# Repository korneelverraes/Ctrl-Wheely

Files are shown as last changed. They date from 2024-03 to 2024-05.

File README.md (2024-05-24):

# Ctrl-Wheely
*Optimalisatie van autodashboard-interactie door middel van een fysieke verplaatsbare knop in de middenconsole en een head-up display.* 

*Projectteam: Korneel Verraes; Warre Robbe*

24/05/2024

## Samenvatting
De nieuwe generatie auto's worden steeds meer uitgerust met slimme dashboards die een breed scala aan functies en flexibele interacties bieden. Grote touchscreens en weinig fysieke knoppen vinden hun weg in het ontwerp van nieuwe wagens. Dit ten gevolge van een besparing in de productie en een trend die bij de consument in goede aarde valt. Dergelijk ontwerp zorgt echter wel voor de nodige onveiligheid en afleiding. Ons doel: het dashboard herontwerpen met de gebruiker en zijn veiligheid in de belangstelling. Of, op welke (gebruiksvriendelijke) manier kunnen we de functies in het dashboard bedienen zonder onze focus op de weg te verliezen?

Wetenschappelijke artikels, _contextual inquiries_ en gebruikersbevragingen tonen aan dat de afleiding niet veroorzaakt wordt door de touchscreens zelf, maar door het gebrek aan tactiele feedback bij het bedienen van een touchscreen.

Met Ctrl-Wheely introduceren we een innovatief, gebruiksvriendelijk en veilig herontwerp van het autodashboard. Een combinatie van een head-up display (HUD), fysieke verplaatsbare knop en controlepaneel moet de bediening sneller en veiliger maken terwijl de ogen op de weg gehouden worden. De afleiding wordt hierbij tot een minimum beperkt.

<p align="center">
  
  
  
</p>

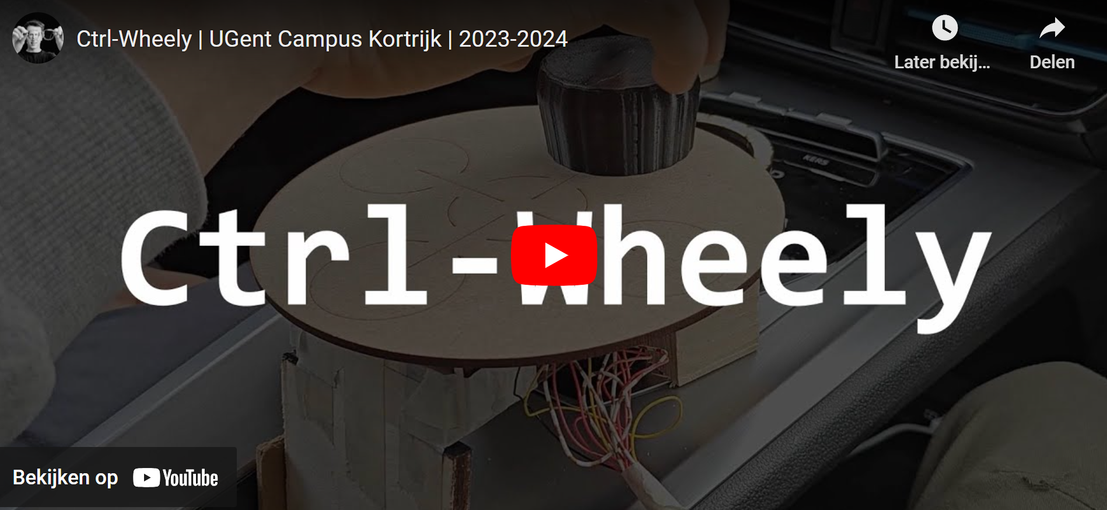
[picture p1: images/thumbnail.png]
[](https://www.youtube.com/watch?v=vWs9MYro9L0)

> [!NOTE]
> - Links naar volledige protocollen en reports zijn te vinden onder de [bijlagen](#bijlagen).
> - Ruwe data zoals foto's, video-opnames, _timetables_... zijn te vinden in de bijhorende protocollen en reports.
> - Volledige software, programma's en 3D-bestanden zijn te vinden in de map [files](/files).

## Introductie
In de hedendaagse auto's zijn touchscreens de standaard geworden, waarbij bestuurders verschillende functies bedienen, variërend van navigatie tot entertainment. Echter, het toenemende gebruik van touchscreens in auto's heeft zorgen gewekt over de veiligheid, met name de visuele afleiding die het met zich meebrengt. Een artikel van de VRT[^1] benadrukt dit probleem en stelt dat het bedienen van touchscreens in de auto drie keer gevaarlijker kan zijn dan rijden onder invloed. Het vermindert aanzienlijk de reactietijd van bestuurders en het risico op ongevallen vergroot.

> "Alternatieven zijn de bediening via knoppen op je stuur of schermen die synthetische feedback leveren, zoals een trilfunctie op je smartphone, als bevestiging dat je opdracht is uitgevoerd zodat visuele verificatie niet meer nodig is."

In 2020 voerde het gerenommeerde Britse instituut, *Transport Research Laboratory (TRL)*, een onderzoek[^2] uit naar de impact van het gebruik van aanraakschermen, Apple CarPlay en Android Auto op het rijgedrag van automobilisten. TRL heeft zijn onderzoeksresultaten getoetst aan de richtlijnen van de Amerikaanse *National Highway Traffic Safety Administration (NHTSA)* met betrekking tot afleiding door elektronische apparaten in voertuigen. Uit deze analyse blijkt dat het handmatig bedienen van touchscreens tijdens het rijden als potentieel onveilig wordt beschouwd. Bediening via spraakherkenning wordt volgens deze richtlijnen net als veilig beschouwd.

Granstudio, een gereputeerd mobiliteitsonderzoek- en ontwerpstudio challenged ons om het autodashboard van de toekomst te ontwerpen. Welke informatie moet weergegeven worden en hoe kan dat veilig gedaan worden?

**Op welke (gebruiksvriendelijke) manier kunnen we de functies in het dashboard bedienen zonder onze focus op de weg te verliezen?**

Randvoorwaarden:
- veilig
- gebruiksvriendelijk
- intuïtief
- interactief

Tijdens het volledige proces zal de gebruiker steeds centraal staan. Er wordt niet enkel rekening gehouden met de eindgebruiker, maar ook met verschillende andere stakeholders. Om tijdens het proces steeds de belangen van de stakeholders te waarborgen zijn ze samengevat in een stakeholder mapping. De drie belangrijkste stakeholders zijn uitgebreider geanalyseerd in de innovatrix. 

<p align="center">
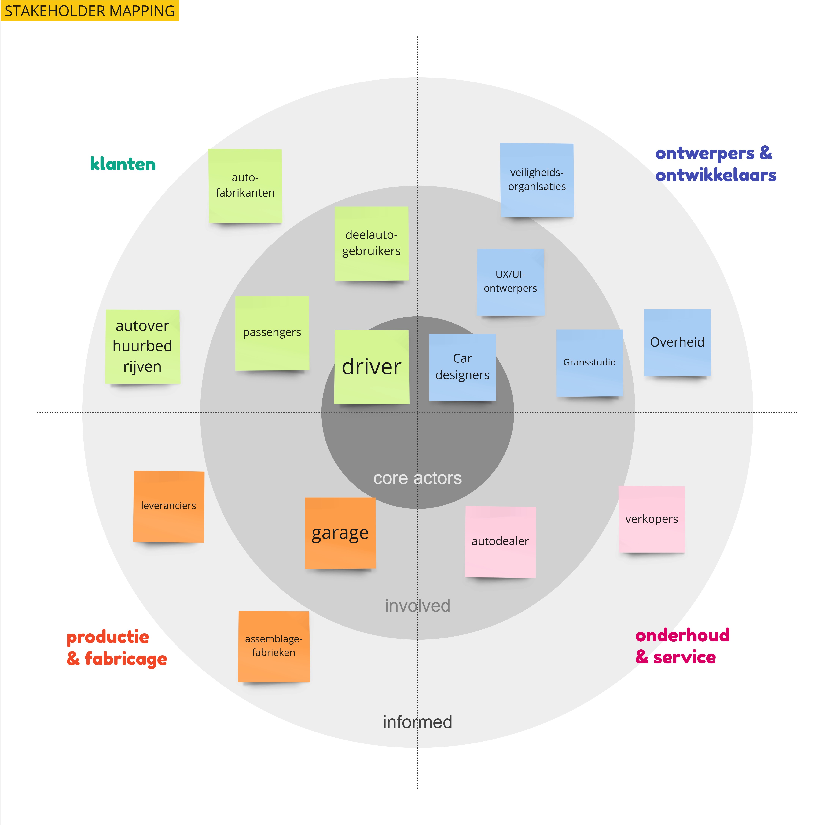
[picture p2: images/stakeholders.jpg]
  
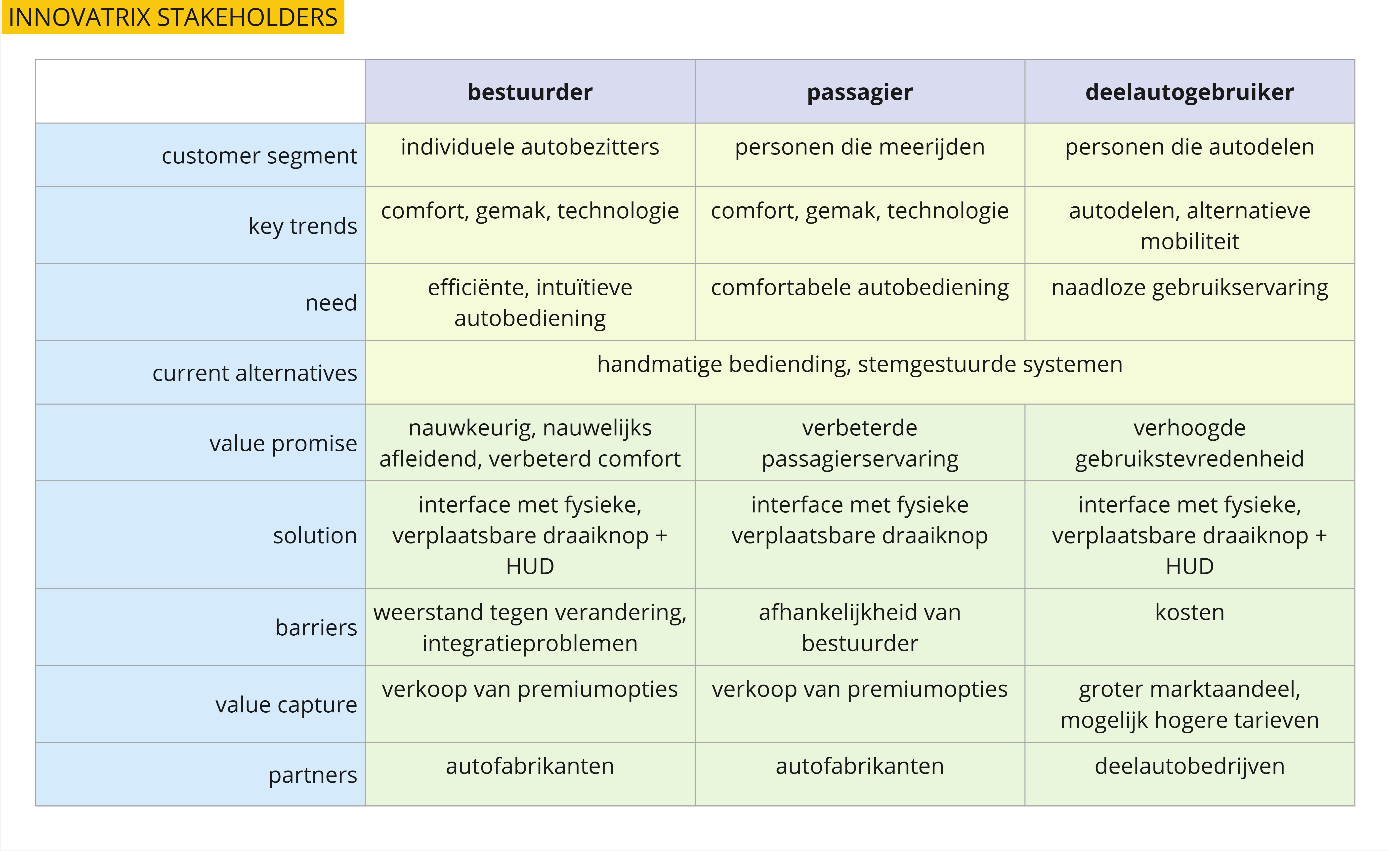
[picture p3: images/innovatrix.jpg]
  
</p>

## Methodologie
Elk ontwerpproces start met de exploratie van de opdracht. Wat is de opdracht? Is het gestelde probleem ook daadwerkelijk een probleem, en vooral, kunnen we dit probleem onderbouwen of weerleggen met bestaande en nieuwe onderzoeken? Onze opdracht startte met een ontmoeting van de opdrachtgevers van dit project. We gingen in gesprek met Granstudio en kregen te horen wat van ons verwacht werd.

In de ontdekkingsfase ontdekken we wat gebruikers, die zich al langere tijd in de probleemruimte bevinden, van het gestelde probleem vinden en welke oplossingen zij in gedachten hebben? Het probleem werd alvast sterk bevestigd in enkele contextual inquiries en ook uit een focusgroep kwamen al enkele interessante opmerkingen. Door te kijken naar wat vandaag de dag al op de markt is (benchmarking) en te overleggen met medestudenten konden we in de oplossingsruimte al het een en ander gaan ontdekken. Met dit onderzoek als basis startten we als team met het uitwerken van een concept binnenin de oplossingsruimte.

In de definitiefase verdiepen we ons in het probleem, met fascinatie voor het probleem en niet voor onze eigen oplossing maken we eerste prototypes en trekken we al snel naar de eerste gebruikers. Met hun feedback passen we aan en gaan we verder. Dat is zowat de hoofdstrategie van ons iteratief ontwerpproces. Via een _storytelling_ en gebruikerstesten krijgen we meer inzicht in de gebruiker. Wat zijn de noden van onze gebruikers en hoe vertaalt zich dat in onze oplossing? Na elke test en elk onderzoek stellen we de nodige _design requirements_ op die doorheen het hele proces van tel zijn.

In de definitiefase concentreren we ons op het testen in een realistische context. We zetten nog sterker in op een _user centered design_. Ctrl-Wheely wordt nu steeds concreter, toch blijven we objectief toekijken naar de inzichten van de gebruikers en mensen daarbuiten. Na een interessant _industry consult_ stuitten we op een nieuw concept dat ons product naar een hoger en gebruiksvriendelijker niveau kan tillen. Niet ideaal op het einde van het proces, doch blijven we ervan overtuigd dat het gebruiksgemak en de veiligheid van de gebruiker voorop staat. We kozen voor een ommezwaai in de conceptkeuze. Na drie boeiende testfases met elk hun eigen focuspunt komen we tot een finaal concept en een productvideo.

Het ontwerpproces en de daarbij horende eindconclusies zijn te lezen in dit verslag. De ontwerpmethodologie van het proces is vastgelegd in deze visuele tijdlijn. 

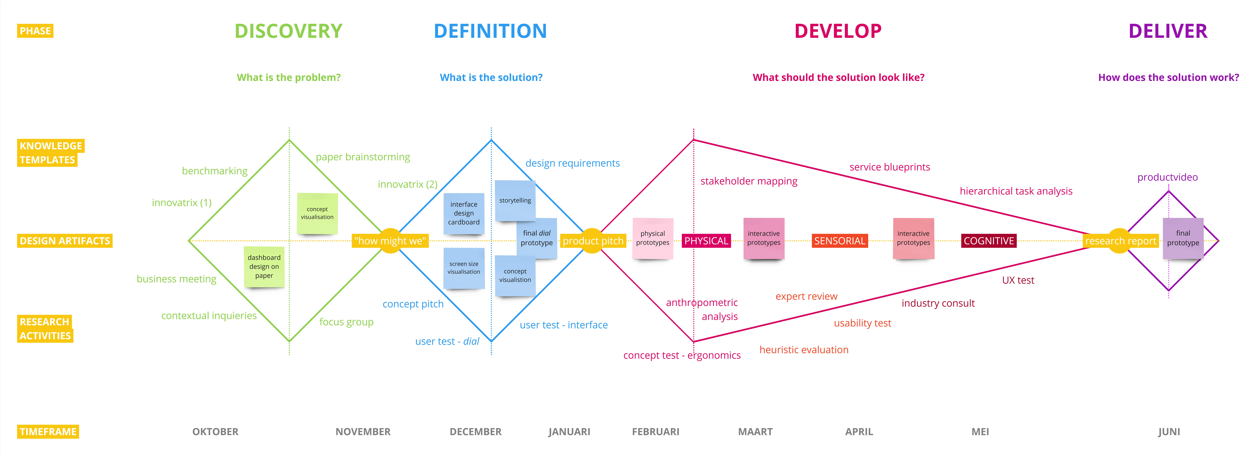
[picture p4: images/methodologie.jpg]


## Discovery (N=21)
Tijdens de ontdekkingsfase streven we ernaar om een helder beeld te krijgen van de probleemruimte en op zoek te gaan naar opportuniteiten. Deze opportuniteiten ontstaan zowel uit gebruikersinzichten, als uit een marktanalyse. Het probleem waarop we focussen wordt met andere woorden scherpgesteld en onderzocht.

### Doelstellingen
Een helder geformuleerde _"how might we"_ bekomen.

### Materiaal & methoden
- _contextual inquiries_
- focusgroep
- benchmarking

### Resultaten
#### Contextual inquiries (N=3)
Door middel van contextual inquiries kunnen we huidige gebruikspatronen in hun natuurlijke context begrijpen, pijnpunten definiëren en een beter begrip krijgen van de contextuele randvoorwaarden.

Om dit te realiseren trokken we de baan op met verschillende autobestuurders. We startten met een introductie om een beter beeld te krijgen van de deelnemer. Daarna werd hem/haar gevraagd verschillende opdrachten uit te voeren; zijn/haar favoriete liedje opleggen, volume verhogen, verwarming verlagen, navigeren met de gps... We hebben alles geobserveerd en een tabel opgesteld met de verschillende functies en hoe ze bediend worden.

<p align="center">
  
  
</p>

||Buttons on steering wheel|Physical buttons|Touchscreen|Voice commands|
|---:|:---:|:---:|:---:|:---:|
|Volume|X|X - X|
|Air conditioning||X|X - X - X|
|Seat heating||X|X - X - X|
|Steering wheel heating|||X - X|
|Navigation|||X - X|X - X|
|Music|||X - X - X|X - X|
|Answering calls|||X - X - X|
|Start calls|||X - X|X|

#### Focusgroep (N=8)
Voor we als team verder gingen had Warre ook al een focusgroep georganiseerd. Die focusgroep ging ook over de veiligheid en afleiding in wagens, specifiek  toegepast op het interieur van elektrische auto’s. Ook uit die focusgroep kwamen enkele interessante topics. Aan acht mensen werd de opdracht gegeven om hun ideale dashboard samen te stellen met allerlei verschillende interieuronderdelen. Zes van de acht gebruikers plaatsten een draaiknop in hun interieur en twee mensen plaatsten er zelf meerdere waaronder ook op het stuur. Dat ze geliefd zijn bij een grote groep mensen is dus alvast zeker. Zes mensen kozen ook om een HUD te plaatsen in de voorruit.

> "Ik ben enthousiast over de minimalistisch interface van een Tesla-interieur, maar anderzijds stel ik mij toch wel vragen bij de functionaliteit en veiligheid van één groot touchscreen zonder fysieke knoppen."

Een ander interessant aspect dat aangehaald werd was het veilig versturen van sms’en achter het stuur. Een alternatief op spraakbediening wanneer deze niet optimaal zou werken is het kiezen tussen vaste berichten die je via ons concept zou kunnen lezen op het HUD. Scrollen en selecteren gebeurt dan met de _dial_.

<p align="center">
  
  
</p>

#### Benchmarking (N=10)
Om de markt te analyseren maken we gebruik van benchmarking, heel wat designkeuzes zijn vaak al succesvol opgelost door anderen. Je hoeft niet alles opnieuw te onderzoeken, maar door bestaande oplossingen aandachtig te bestuderen kunnen we focussen op meer belangrijke onbekende factoren.

Het probleem werd opgesplitst in twee fundamentele deelproblemen. Hoe kunnen we informatie weergeven en hoe kunnen we bepaalde functies bedienen? Voor beide werden de voor- en nadelen op een rijtje gezet. Daarna werd alles samengegoten in een overzichtelijke *problem-solution* matrix.

<p align="center">
  
  
</p>



### Conclusies & implicaties
De afleiding tijdens het rijden wordt niet veroorzaakt door het touchscreen zelf, maar door het gebrek aan tactiele feedback bij het bedienen van het scherm. Je moet visueel verifiëren wat je gedaan hebt en of je het juist gedaan hebt. Verder genieten knoppen op het stuur en bediening via het touchscreen de voorkeur van gebruikers, gevolgd door fysieke knoppen en stembediening.

HUD's die in de voorruit of op de onderste zwarte band van de ruit geplaatst worden tonen informatie zonder dat de bestuurder zijn ogen van de baan hoeft te halen, wat de veiligheid bevordert. 3D-schermen en hologrammen bieden een goede ervaring en een grote aanpasbaarheid, maar zijn over het algemeen kostbaarder en complexer. Augmented reality-schermen combineren digitale informatie met de echte wereld, wat de navigatie- en veiligheidskenmerken verbetert. Traditionele schermen kunnen ondanks dat ze kosteneffectief en vertrouwd zijn de aandacht van de weg brengen. Fysieke knoppen en knoppen op het stuur geven prioriteit aan tastbare feedback en minimale afleiding, terwijl aanraakschermen en spraakbesturing veelzijdigheid bieden, maar mogelijk ten koste gaan van de veiligheid. Context, compatibiliteit en de leercurve zijn ook belangrijke factoren om in overweging te nemen.

**Hoe kunnen we een _dial_ en een HUD gebruiken om afgeleide bestuurders gefocust te houden op de weg, terwijl ze interageren met het dashboard?**

> [!IMPORTANT]
> Design Requirements:
> - D3.1 Het touchscreen laat toe de functies en hun bijhorende posities onderling te wijzigen.
> - D1.1 Het product laat toe functies te bedienen zonder dat de ogen van de baan afwijken.
> - D2.1 De _dial_ geeft haptische feedback bij het bedienen van de functies.

## Definition (N=11)
In de definitiefase geven we vorm aan de oplossingen die we dit jaar zullen uitwerken. Gebruikmakend van het eerder gedefinieerde probleem, onderzoeken we mogelijke oplossingen om zo een weloverwogen conceptkeuze te maken. Dit concept dient dan als basis voor verdere ontwikkeling in het tweede semester.

### Doelstellingen
Tot een conceptueel ontwerp komen.
- thematische schets
- _storyboard_
- _quick-and-dirty_ prototype

### Materiaal & methoden
- _sensorial boards_
- kartonnen prototypes
- digitaal ontworpen interfaces
- gebruikersinterviews
- gebruikerstesten

### Resultaten
#### Dial (N=6)
Door het uitvoeren van concepttesten kunnen we ons concept evalueren met echte gebruikers. Hierdoor kunnen we ook het gedrag van de gebruiker tijdens de interactie observeren en analyseren.

Het doel van deze concepttest is een conceptueel ontwerp te hebben voor onze _dial_. Welke grootte? Welke vorm? Welk materiaal? Na een korte introductie gaven we elke deelnemer een stuk klei/plasticine. We gaven hen de opdracht om hun ideale _dial_ te ontwerpen en hierbij te variëren in vorm, grootte, afwerking... Hierbij moest de focus op het praktische aspect liggen, minder op het esthetische. Nadat elke deelnemer zijn of haar ideale _dial_ gemaakt had gingen we over naar het tweede deel van de test. We ontwikkelden drie *sensorial boards*: 6 verschillende groottes, 9 vormvarianten en 6 verschillende materialen. Elke deelnemer kreeg de kans elk bord te exploreren door aan de verschillende modellen te voelen. Per bord moesten de deelnemers hun voorkeur weergeven in een top 3. Alle ruwe data van deze testen werd verzameld door middel van gebruikersformulieren.

<p align="center">
  
  
</p>

<p align="center">
  
  
  
</p>

<p align="center">
  
  
  
  
</p>

Na de test werden alle formulieren verzameld en geanalyseerd. De resultaten van de opgestelde top 3's werden samengegoten in een scoringsmatrix. Prototypes op plaats 1 kregen een score +3, prototypes op plaats 2 kregen een score +2 en prototypes op plaats 3 kregen een score +1. Prototypes waar deelnemers eerder een afkeur voor hadden, kregen een -1. Door de scores voor elk model van alle deelnemers bij elkaar op te tellen, hebben we een eindscore afgeleid. Een hogere eindscore duidde op een gunstigere ervaring.

<p align="center">
  
  
  
</p>

#### User interface (N=5)
Uit de eindscores van de eerste gebruikerstesten konden we met de meest ideale _dial_vorm opnieuw naar de gebruiker trekken. Deze keer werd bewust gekozen voor nieuwe testpersonen. Door het kiezen van nieuwe testpersonen kunnen er nieuwe visies ontstaan en kunnen we al dan niet bevestigd krijgen of de gebruiker ons concept begrijpt.
Met deze test richten we ons op de conceptuele interactie van de _dial_functies en een interface. In het tweede semester zetten we deze resultaten om in een functioneel en interactief ontwerp.
We trokken naar de gebruiker met drie schermgroottes gevisualiseerd op dibond (een glad aluminium-kunststofplaat), zes verschillende interfaces geprint op papier, een werkende interactie-interface - gemaakt in Figma - en natuurlijk de _dial_.
Na een korte toelichting volgden er al enkele positieve reacties op het concept en kwamen er enkele interessante opmerkingen. Daarna mocht iedereen kiezen tussen drie schermgroottes, wel met de functie van de _dial_ in hun achterhoofd.
Ze kregen ook zes interfaces voorgeschoteld waarvan ze een top drie mochten maken en eventueel een interface als onbruikbaar voor het concept markeren.

<p align="center">
  
  
  
</p>

<p align="center">
  
  
  
</p>

### Conclusies & implicaties
Uit de klei-test blijkt dat gebruikers een voorkeur hebben voor kleinere knoppen, echter vermelden een aantal deelnemers dat hun voorkeur gaat naar een knop met voldoende volume en grip. De groottes variëren niet zo heel veel, maar de vormen wel, gaande van klassieke cilinders tot schuivers en bolvormige knoppen.

> "Eventueel kan de knop conisch gemaakt worden. Dit zorgt niet enkel voor meer grip maar geeft mij ook het signaal dat de knop verplaatst kan worden."

Uit de scoringsmatrix blijkt dat een knop met een diameter van 60 mm en een hoogte van 20 mm het meest geschikt is, ook de licht hogere _dial_ werd positief bevonden. Daarnaast gaat de voorkeur qua vorm naar een gegolfde contour. Op vlak van materiaal prefereren de deelnemers een licht indrukbaar materiaal, maar ook de ruwere materialen vallen in de smaak.

Samengevat:
- dubbele conische vorm
- diameter 55 mm
- hoogte 30 mm
- geribbelde contour
- rubberachtig materiaal (nog te exploreren via 3D-printen)

Uit de interfacetest blijkt dat onderstaande interface als het meest aangenaam, modern, intuïtief en gebruiksvriendelijk aanvoelt. De interactie met de _dial_ moet niet noodzakelijk visueel verduidelijkt worden. Volgens de gebruikers is het slechts een gewoontekwestie om de interactie met de _dial_ en het scherm te begrijpen.
Gebruikers beschouwen de mediummaat (350 x 215 mm) van het touchscreen als meest ideaal. Het is noodzakelijk dat die niet te klein is om gemakkelijk met de _dial_ te kunnen interageren op verschillende plaatsen op het scherm. De belangrijkste functies zijn vooral de standaardfuncties zoals temperatuurregeling, muziek, volume en navigatie. Met zes mogelijke posities op ons scherm, en dus zes bedienbare functies tijdens het rijden, zitten we goed.

> "Net zoals in mijn BMW zou ik het handig vinden dat de _dial_ ook naast het scherm bedienbaar is zodat ik niet telkens met mijn hele arm tot het scherm hoef te reiken."

Het is belangrijk rekening te houden met verschillende armlengtes. Het scherm mag niet te ver zijn en is best gericht naar de bestuurder. Dit zet ons aan het denken om een kantelbaar scherm te integreren waarbij beperkingen opgelegd worden aan de hand van de richting van het scherm (bestuurder vs passagier)...

<p align="center">
  
  
</p>

> [!IMPORTANT]
>  Design Requirements:
> - D1.2 Het product laat toe zes functies veilig te bedienen tijdens het rijden.
> - D1.3 Het product is voor 95% van de mensen op elke mogelijke positie comfortabel toegankelijk.
> - D2.2 De _dial_ heeft een conische vorm.
> - D2.3 De _dial_ ligt voor 95% van de mensen goed in de hand.
> - D2.4 De _dial_ kan ook naast het scherm bediend worden.
> - D3.2 Het touchscreen is goed leesbaar.
> - D3.3 Het touchscreen oogt modern.

## Prototype
In onderstaande renders en _storytelling_ is te zien hoe het concept er op dit moment uitzag en hoe het product gebruikt wordt. Een fysieke verplaatsbare knop die je op het touchscreen kan plaatsen. Elke plaats op het scherm representeert een bedienbare functie. De combinatie met een HUD zorgt ervoor dat de ogen niet van de baan afwijken. In tegenstelling tot de standaard fysieke knoppen kun je met zo'n _dial_ toch een breed scala aan functies gaan bedienen, met behoud van de tactiele feedback. Ook het touchscreen is er nog steeds voor wanneer men stilstaat of voor de passagier.

<p align="center">
  
  
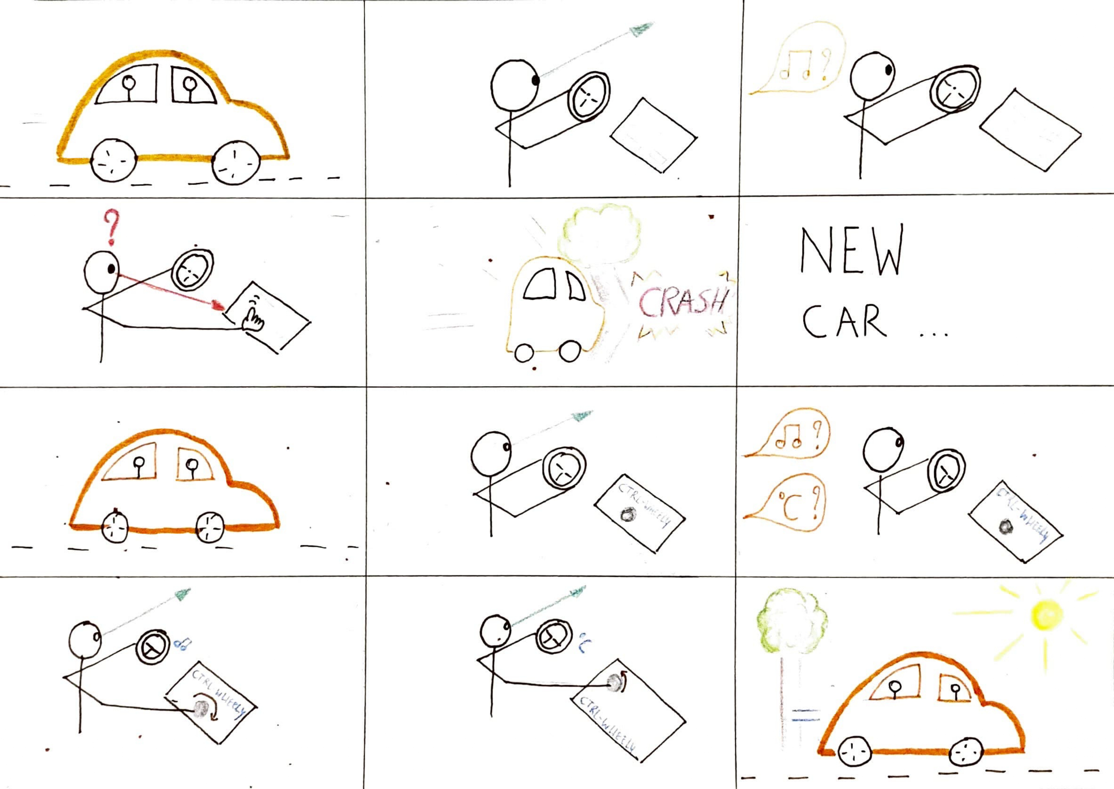
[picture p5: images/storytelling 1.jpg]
  
</p>

Tot nu toe werd er nog niet zoveel aandacht besteed aan een prototype. Alvorens de volgende gebruikerstesten te starten was daar wel nood aan. Zo'n prototype is van groot belang om de validiteit van een test te vergroten. Het concept dat op dit moment in ons hoofd speelt is een touchscreen met daarop een knop. We gebruiken hier de methode van het quick en dirty prototype. Het nut van dit prototype is het concept concreter maken en duidelijk te maken aan de gebruiker.

Het gebruik van een reëel touchscreen is in deze fase van het proces nog niet aan de orde. Bovendien zijn de grootte, functionaliteiten, vorm... nog niet beslist. De uitgewerkte interface (Figma) printten we af en kleefden we op een dibondplaat. De eerstvolgende test heeft betrekking tot de ergonomische afmetingen. Hiervoor was het noodzakelijk dat het touchscreen op verschillende posities in de auto gemonteerd kon worden. We gebruikten kartonnen tussenstukken en papierplakband om dit snel te realiseren. De knop, nu nog zonder draai- en klikfunctionaliteit, werd gemaakt met de 3D-printer.

Om toch al enige vorm van interactie te bieden tijdens de test werden er een magneet in de knop en metalen plaatjes achter het touchscreen geïntegreerd. Dit zorgde al voor het gevoel van de _snapping points_ om de juiste functie blindelings te kunnen selecteren.

<p align="center">
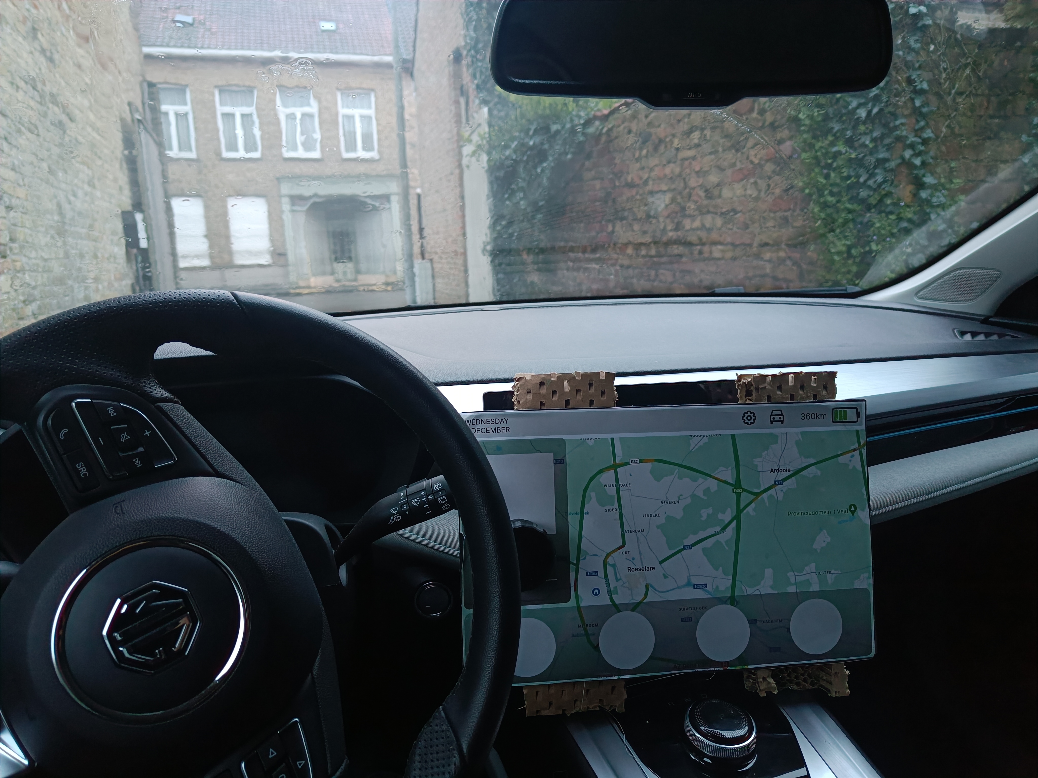
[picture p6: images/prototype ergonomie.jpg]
  
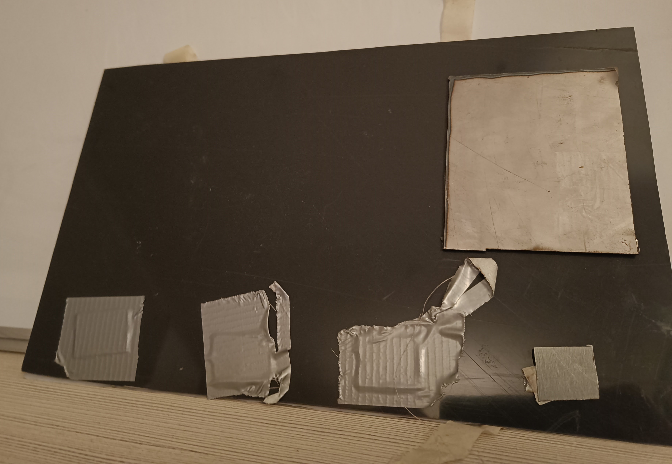
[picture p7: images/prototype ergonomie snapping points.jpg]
  
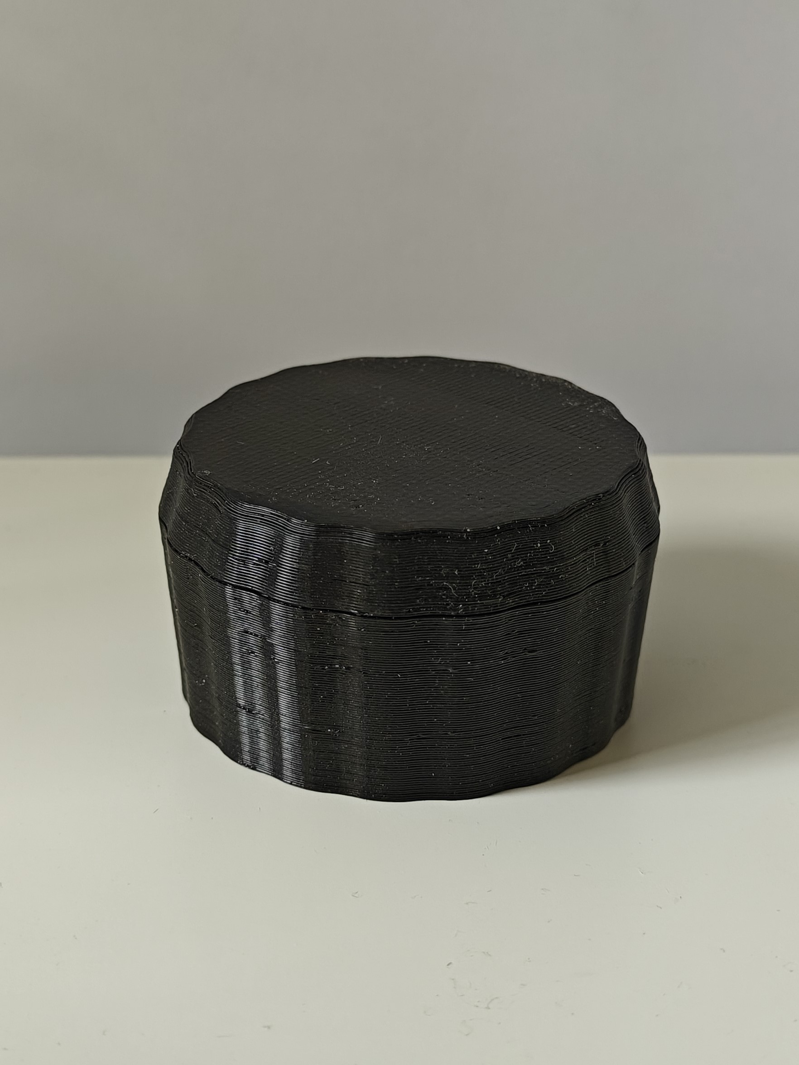
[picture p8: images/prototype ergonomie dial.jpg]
  
</p>

## Develop 1: Human Body (N=5)
Het eindpunt van deze eerste ontwikkelingsfase is een geoptimaliseerd ontwerp, waarvan we aan de hand van een antropometrische analyse en gebruikerstest kunnen aantonen welke optimalisaties we hebben aangebracht op het vlak van fysieke ergonomie.

### Doelstellingen
- De theoretisch onderzochte ergonomische afmetingen praktisch verifiëren.
- Bekomen van definitieve afmetingen van het touchscreen tot aan de gebruiker.
- Al dan niet bevestigen of de _dial_ overal en in elke situatie comfortabel te besturen is.
- Interface bijstellen voor een optimale ergonomie.

### Materiaal & methoden
Bij de antropometrische berekeningen baseren we ons op de DINBelg database[^3]. De afstand die we wensen te bepalen is de afstand van de rugleuning tot de uiterste positie op het touchscreen. Dit komt overeen met de reikdiepte (17). We willen de positie van ons scherm optimaliseren voor 95% van de gebruikers. Omdat het scherm op de dichtste afstand ook bedienbaar is door de grootste mensen maken we hier de keuze voor de designstrategie: _design for the small_.  Bijgevolg berekenen we P5 van de populatie.

- Uit de database:
  - µ = 767 mm
  - σ = 50 mm
- Berekening:
  - 5% → z = -1,645  
  - P5 = µ+z∙σ = 767-1,645∙50 = 685 mm 

Als de stoel van de bestuurder zo staat dat die ideaal is voor de 5% kleinste gebruikers, dan bedraagt de afstand tussen de rugleuning en de uiterste positie op het touchscreen maximaal 685 mm. Grotere bestuurders zullen de stoel meer naar achter verplaatsen waardoor ook de voorgenoemde afstand mee zal vergroten. 

De testpersonen kregen allen de opdracht hun zetel zo te positioneren zoals ze dat gewoonlijk zouden doen, ongeacht de afstand tot het touchscreen. Daarna vroegen we hen na te gaan of de uiterste positie van het scherm voor hen goed bereikbaar was met de _dial_. Op de interface mochten ze ook vooraf bepalen waar ze welke functie zouden plaatsen en waarom. Met die vooraf bepaalde functies mochten ze een toer rijden met de wagen en de _dial_ bedienen. Hierbij kregen ze van ons de opdracht om verschillende dingen te bedienen. Zo konden we controleren hoe rap de plaats van de functies went en of de bestuurder het nodig acht om de ogen van de weg te halen. We begeleidden hen door te zeggen wat ze aan het bedienen waren.

Er werd een elektrische wagen gebruikt om de testomgeving zo realistisch mogelijk te maken.
    
### Resultaten
We maakten gebruik van grotere en kleinere testpersonen. Dit was vooral interessant om onze eerdere theoretische berekeningen te controleren. Het eerste deel van de test bewees dat een dichter touchscreen (_design for the small_) niet zorgt voor problemen bij grotere mensen doordat zij ook hun zetel meer naar achter zetten. We maten telkens de lichaamslengte en de afstand vanaf de uiterste positie van het touchscreen tot de zetel. Dat laatste staat gelijk aan de uitgestrekte lengte van de arm zonder dat de testpersoon naar voor hoeft te komen. Onderstaande resultaten kwamen uit die metingen.

|Lichaamslengtes (cm)|Uitgestrekte armlengtes (scherm - rugleuning) (cm)|
|:---|:---|
|165|71|
|168|72|
|178|78|
|184|79|
|201|83|

Elke positie lijkt voor de gebruikers goed bereikbaar met de _dial_. Grote gebruikers zaten soms wel met hun knieën tegen het touchscreen, als we het touchscreen een beetje naar rechts schoven (zoals we ook voor de andere gebruikers daarna deden) was dit probleem grotendeels van de baan. Toch blijkt dat de uiterst linkse positie besturen met de _dial_ onaangenaam en niet makkelijk aanvoelt. Dit werd door meerdere testpersonen aangehaald en het overgrote deel van de testpersonen had ook de wens om het muziekvak rechts te plaatsen omdat dit makkelijker te besturen is. De functie die het makkelijkst te bedienen is vanuit de bestuurderszetel, was unaniem de meest rechtse. Als we de testpersonen vroegen tijdens het rijden het volume te veranderen, merkten we dat ze vaak naar de muziekfunctie grepen om het volume aan te passen. Als er gevraagd werd om de muziek te verzetten hadden de gebruikers de neiging om dit met hun vinger (touchbediening) te doen.

Tijdens het rijden werd snel duidelijk dat iedereen dankzij de _snapping points_ perfect wist waar welke functie zat, zonder te hoeven kijken. Alle gebruikers gaven ook aan dat de _dial_ bedienen geen problemen veroorzaakte tijdens het rijden.

> "Het kost maximaal één dag om gewoon te worden waar welke functie zit, zeker als dit personaliseerbaar is."

<p align="center">
  
  
  
</p>

### Conclusies & implicaties
We zijn tevreden dat de theoretisch bepaalde afstand tot het scherm in de praktijk ook goed werkt. Een dichter touchscreen zorgt voor een betere en veiligere bereikbaarheid voor kleinere mensen en heeft geen negatief effect op grotere mensen.

De volumefunctie nemen we weg van het touchscreen, deze wordt bediend door een aparte knop. Hierdoor komt er een positie vrij. We schuiven alles op zodat er uiterst links niets meer bediend hoeft te worden, want die plaats was voor veel personen moeilijk bereikbaar. We werkten ondertussen een nieuwe interface uit die rekening hield met deze ondervindingen.

<p align="center">
  
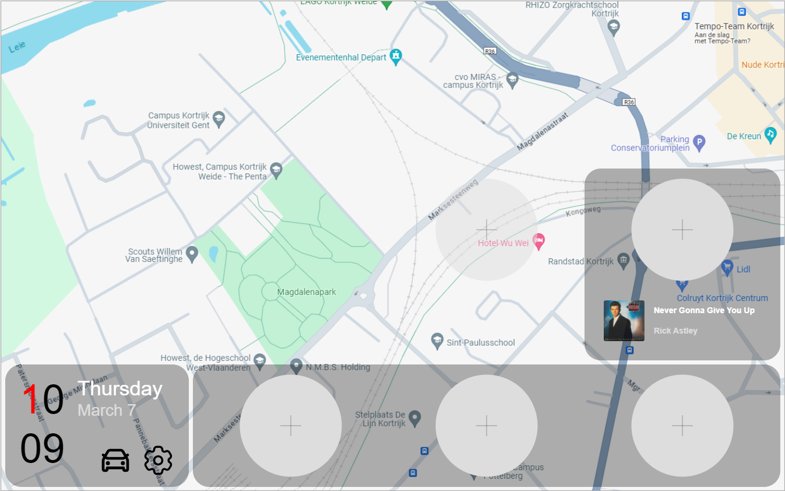
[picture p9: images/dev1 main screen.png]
  
</p>

We kijken terug naar een interessante test. Ons concept werd goed onthaald en alles blijkt snel te wennen. Ook tijdens het rijden ontstaan geen noemenswaardige afleidingen door het touchscreen. Ons doel is nu het HUD verder uit te werken zodat we ons verder kunnen toespitsen op de interactie met de _dial_.

> [!IMPORTANT]
> Design Requirements:
> - D1.4 Het product laat toe het volume met een aparte knop te bedienen.
> - D3.4 Het touchscreen geeft niet de intentie met touch bediend te kunnen worden tijdens het rijden.
> - D3.5 Het touchscreen laat niet toe functies te bedienen binnen 1/4 van de linkerkant.

## Prototype
De volgende stap in de ontwikkeling van het prototype was de interactie. Tot nu toe was ons prototype vrij statisch. We wilden graag wat dynamiek toevoegen om de validiteit van de gebruikerstesten te verhogen. Hiervoor maakten we een functionerende _dial_ en een interface voor het HUD. De losstaande volumeknop wordt voorgesteld door een houten cilindertje die op de middenconsole is geplakt.

Om alle interacties te realiseren maakten we gebruik van Arduino's, een encoder, een magneet, magneetsensoren & ProtoPie. Een Arduino in de _dial_ communiceert via bluetooth de rotaties en indrukkingen van de encoder naar een centrale Arduino. Deze centrale Arduino stuurt via seriële communicatie (USB) de data door naar ProtoPie Connect, die de data op zijn beurt doorstuurt (USB) naar de ProtoPie Player op een smartphone (HUD) in de voorruit. Via een magneet in de _dial_ detecteren magneetsensoren achter het touchscreen waar de _dial_ zich bevindt. De data van deze sensoren wordt ook ingelezen en doorgestuurd door een centrale Arduino. Onderstaand schema geeft een visuele representatie van deze communicatie.

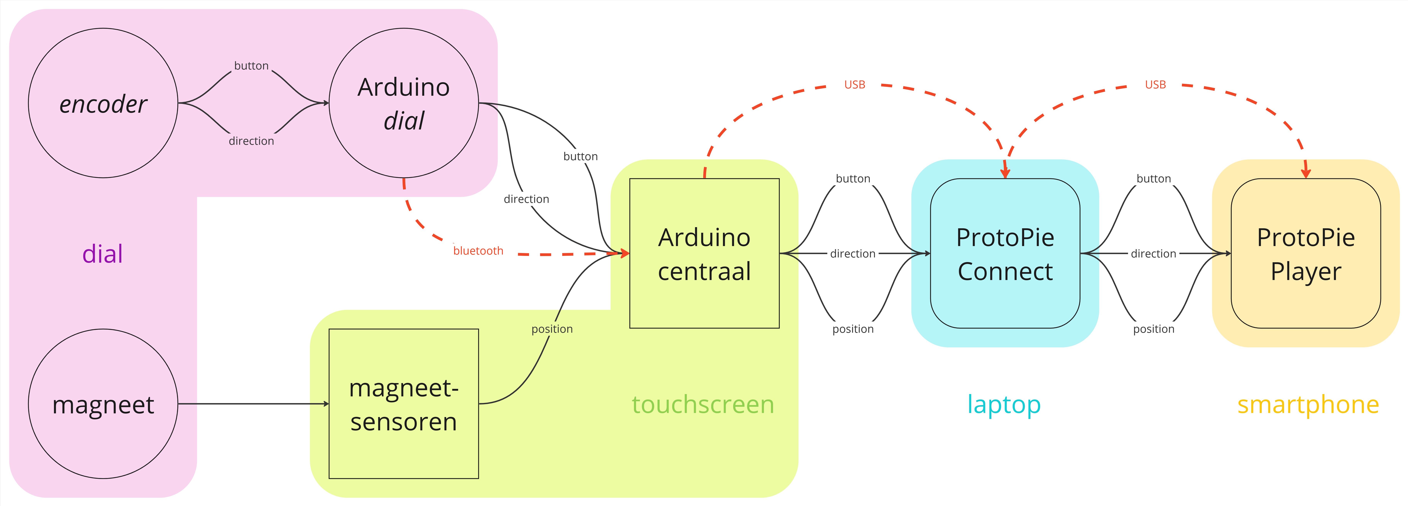
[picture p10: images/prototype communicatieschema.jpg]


### Dial
Het vormelijk ontwerp (grootte, vorm & materiaal) van de _dial_ bleef ongewijzigd, in deze fase werd ze enkel functioneerbaar gemaakt. De _dial_ is hol en bestaat uit twee losneembare delen: een onderkant waar de magneet zit en een bovenkant waar de elektronische componenten gemonteerd zijn. Deze elektronische componenten zijn een incrementele _rotary encoder_, een Arduino Nano 33 IOT en batterijen (2x CR2032). De _dial_ zelf werd gemaakt met de 3D-printer.

Bij de eerste testen met de _dial_ merkten we dat de batterijen voor problemen zorgden. Ze liepen zeer snel leeg en gaven niet voldoende spanning. Hierdoor werden we genoodzaakt de batterijen te vervangen door een externe spanningsbron, de auto zelf (via USB).

<p align="center">
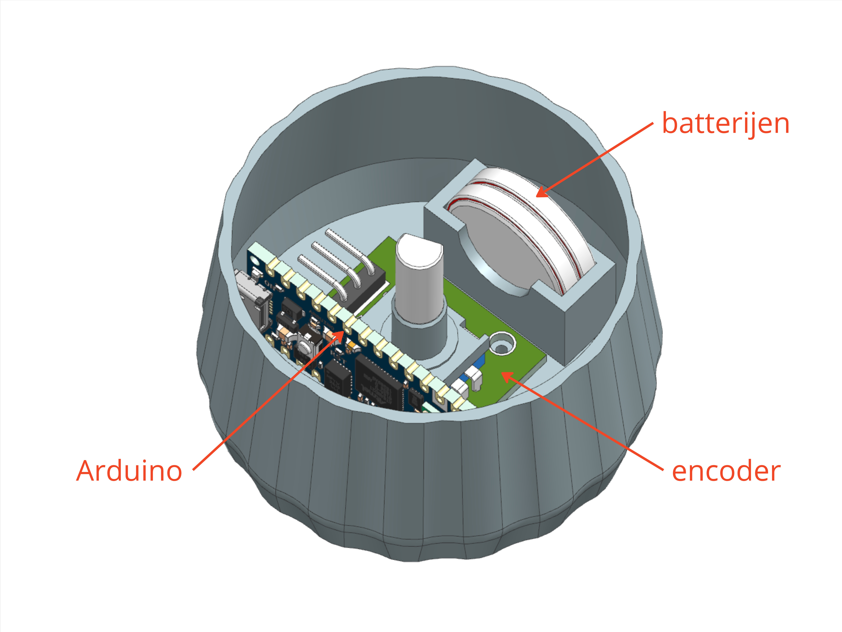
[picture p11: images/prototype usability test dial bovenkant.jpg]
  
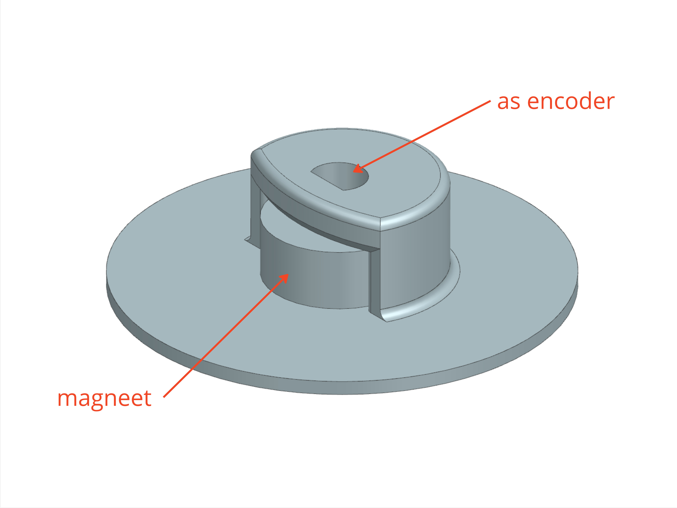
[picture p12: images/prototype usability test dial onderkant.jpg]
  
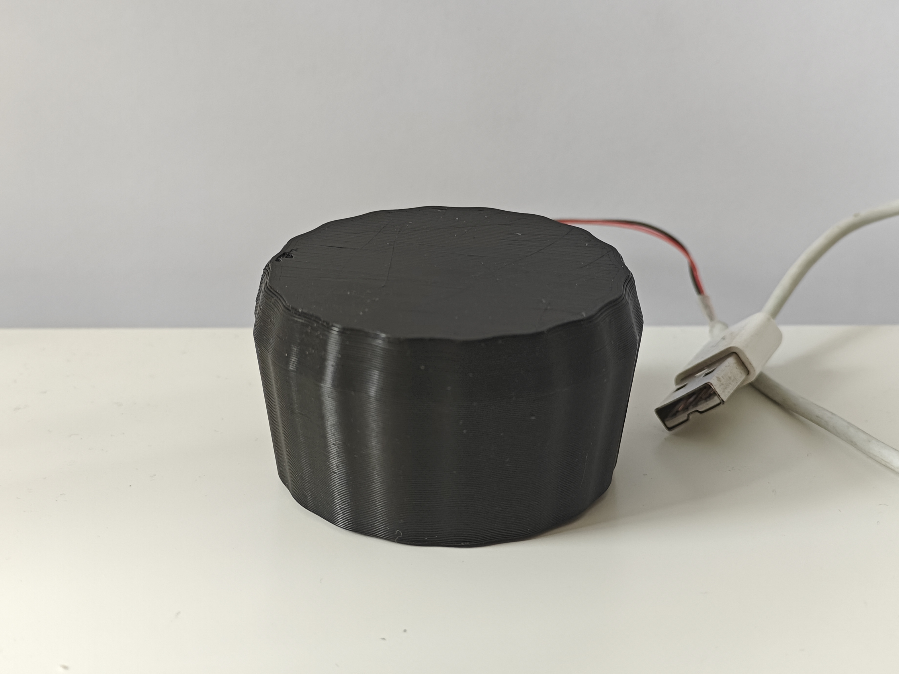
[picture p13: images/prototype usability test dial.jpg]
  
</p>

De _dial_ moet het klikken & draaien registreren en via bluetooth doorsturen naar de centrale Arduino. Onderstaande code werd geprogrammeerd in de Arduino IDE om deze functionaliteiten te realiseren.

```py
#include <ArduinoBLE.h>

int buttonPin = 3;
int encoderAPin = 2;
int encoderBPin = 4;

int buttonState = 0;
int ButtonLastState = -1;
int encoderState = 0;
int encoderLastState = -1;
int direction = 0;
int lastDirection = -1;

void setup() {
  Serial.begin(9600);
  pinMode(buttonPin, INPUT);
  pinMode(encoderAPin, INPUT);
  pinMode(encoderBPin, INPUT);
  BLE.begin();
  Serial.println("Bluetooth® Low Energy Central - dial");
  BLE.scanForUuid("19b10000-e8f2-537e-4f6c-d104768a1214");
}

void loop() {
  BLEDevice dial = BLE.available();
  if (dial) {
    Serial.print("Found ");
    Serial.print(" '");
    Serial.print(dial.localName());
    Serial.println("' ");
    if (dial.localName() != "central") {
      return;
    }
    BLE.stopScan();
    outputProtopie(dial);
    BLE.scanForUuid("19b10000-e8f2-537e-4f6c-d104768a1214");
  }
}

void outputProtopie(BLEDevice dial) {
  Serial.println("Connecting ...");
  if (dial.connect()) {
    Serial.println("Connected");
  } else {
    Serial.println("Failed to connect!");
    return;
  }
  Serial.println("Discovering attributes ...");
  if (dial.discoverAttributes()) {
    Serial.println("Attributes discovered");
  } else {
    Serial.println("Attribute discovery failed!");
    dial.disconnect();
    return;
  }
  BLECharacteristic central = dial.characteristic("19b10001-e8f2-537e-4f6c-d104768a1214");

  while (dial.connected()) {
    buttonState = digitalRead(buttonPin);
    encoderState = digitalRead(encoderAPin);

    if (buttonState == 0 && ButtonLastState == 1) {
      Serial.println("button1");
      central.writeValue((byte)0x01);
    }
    ButtonLastState = buttonState;

    if (encoderState != encoderLastState) {
      if (digitalRead(encoderBPin) != encoderState) {
        direction = 0;
        if (direction == 0 && lastDirection == 0) {
          Serial.println("dir0");
          central.writeValue((byte)0x02);
          direction = 1;
        }
        lastDirection = direction;
      } else {
        direction = 1;
        if (direction == 1 && lastDirection == 1) {
          Serial.println("dir1");
          central.writeValue((byte)0x03);
          direction = 0;
        }
        lastDirection = direction;
      }
    }
    encoderLastState = encoderState;
  }
  Serial.println("Peripheral disconnected");
}
```

### Touchscreen
De interface op het touchscreen bleef ongewijzigd. Enkel werden ook hier de functionaliteiten toegevoegd. De metalen plaatjes langs de achterkant werden vervangen door rosse munten omwille van hun ronde vorm en hun sterk magnetische aantrekkingskracht. Op elk van die munten bevestigden we een magneetsensor om de positie van de _dial_ op het touchscreen te detecteren. We monteerden dit fictieve touchscreen in de auto door middel van enkele haken die we met de lasercutter maakten. Deze zorgden ook voor de juiste tussenafstand, bepaald tijdens de vorige gebruikerstest.

<p align="center">
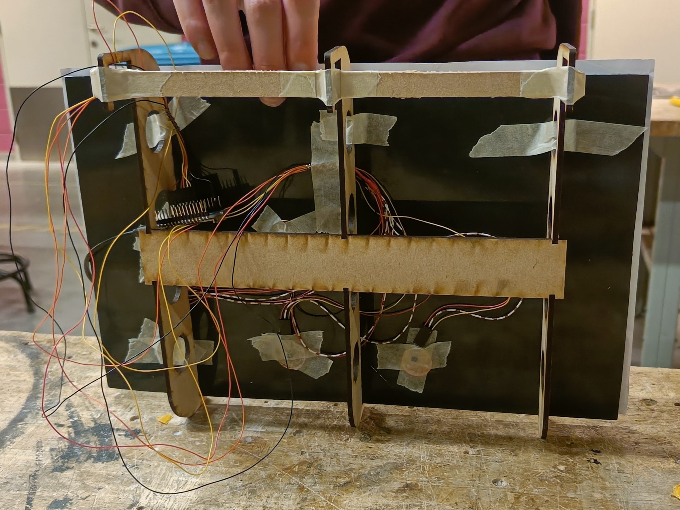
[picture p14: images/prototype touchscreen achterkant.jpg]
  
  
</p>

Achter dit touchscreen bevindt zich ook de centrale Arduino Nano 33 IOT. Deze moet de data van de magneetsensoren & de Arduino in de _dial_ inlezen, en doorsturen naar ProtoPie Connect door middel van seriële communicatie (USB). Onderstaande code werd geprogrammeerd in de Arduino IDE om deze functionaliteiten te realiseren.

```py
#include <ArduinoBLE.h>

BLEService dial("19B10000-E8F2-537E-4F6C-D104768A1214");
BLEByteCharacteristic encoder("19B10001-E8F2-537E-4F6C-D104768A1214", BLERead | BLEWrite);

int sensorPin[] = { A0, A1, A2, A3, A4, A5 };
int sensorValue = 0;

int position = 0;
int lastPosition = 0;

unsigned long t0 = 0;
unsigned long t1 = 0;
unsigned long dt = 5000;

void setup() {
  Serial.begin(9600);

  if (!BLE.begin()) {
    Serial.println("starting Bluetooth® Low Energy module failed!");

    while (1)
      ;
  }

  BLE.setLocalName("central");
  BLE.setAdvertisedService(dial);
  dial.addCharacteristic(encoder);
  BLE.addService(dial);
  encoder.writeValue(0);
  BLE.advertise();
  Serial.println("BLE central");
}

void loop() {
  BLEDevice central = BLE.central();

  if (central) {
    Serial.print("Connected to central: ");
    Serial.println(central.address());

    while (central.connected()) {
      t1 = millis();
      dt = t1 - t0;
      if (encoder.written()) {
        if (dt < 5000) {
          dt = 0;
          t0 = millis();
          if (encoder.value() == 1) {
            Serial.println("button1");
          }
          if (encoder.value() == 0) {
            Serial.println("button0");
          }
          if (encoder.value() == 2) {
            Serial.println("dir0");
          }
          if (encoder.value() == 3) {
            Serial.println("dir1");
          }
        } else {
          Serial.print("pos");
          Serial.println(position);
          dt = 0;
          t0 = millis();
        }
      }
      for (int i = 0; i < 5; i++) {
        sensorValue = analogRead(sensorPin[i]);
        if (sensorValue > 400) {
          position = i;
        }
        //Serial.print(sensorValue[i]);
        //Serial.print(" | ");
      }
      if (lastPosition != position) {
        Serial.print("pos");
        Serial.println(position);
        dt = 0;
        t0 = millis();
      }
      lastPosition = position;

      if (dt >= 5000) {
        Serial.println("home");
      }
    }

    Serial.print(F("Disconnected from central: "));
    Serial.println(central.address());
  }
}
```

### HUD
Alles wat wordt bediend met de _dial_ wordt weergegeven in een HUD. De integratie van een echt werkend HUD is buiten de scope van deze opdracht. Daarom werd deze vervangen door een smartphone in de voorruit. In de realiteit zal het HUD de grootte van een standaardlaptopscherm hebben en zal de helderheid zich automatisch aanpassen aan de omgeving.

<p align="center">
  
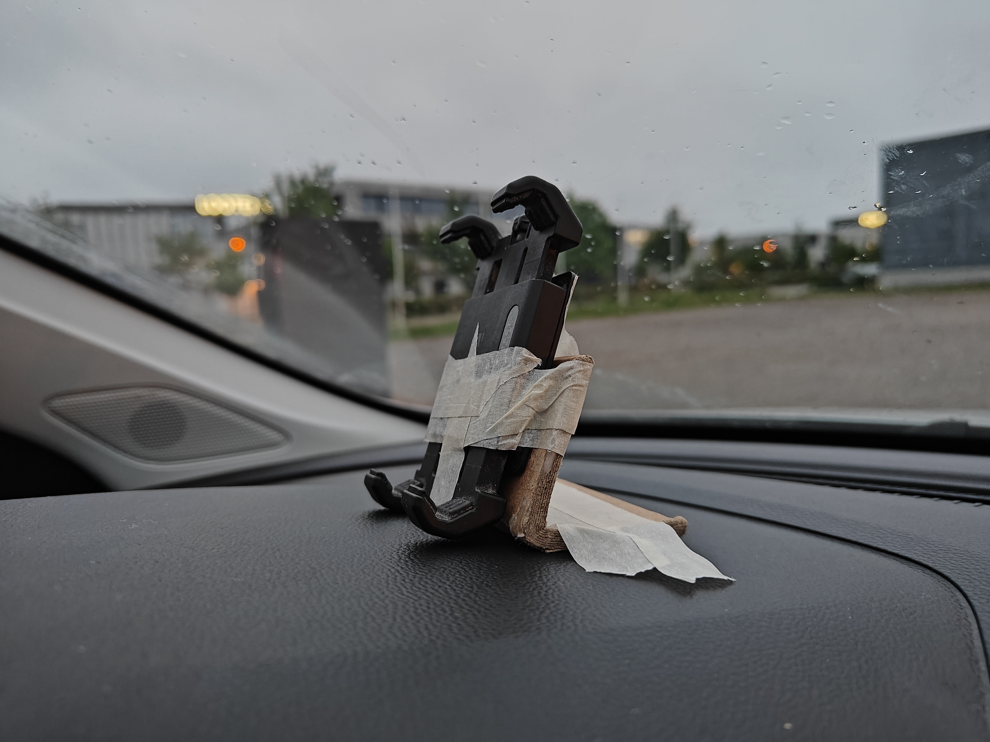
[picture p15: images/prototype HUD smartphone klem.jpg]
  
</p>

Om een interface te ontwerpen maakten we gebruik van ProtoPie. We begonnen met het kiezen van een lay-out:
- links: tijd, temperatuur & navigatie
- centraal: knipperlichten, toegelaten snelheid, huidige snelheid, auto voor jou, _line assist_ & rijbereik
- rechts: weergave van de functionaliteiten die je met de _dial_ aan het bedienen bent

Alles wat donkergrijs is in de interface, is in principe transparant bij een echt HUD. De blauwe lijnen stellen de _line assist_ voor. De auto in het midden is een fictieve auto voor jou. De rechtse weergave (functionaliteiten) verdwijnt indien er 5 seconden niets wordt aangepast.

<p align="center">
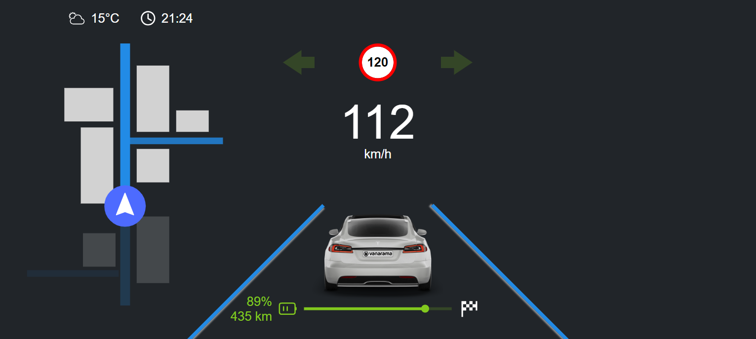
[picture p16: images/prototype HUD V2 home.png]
  
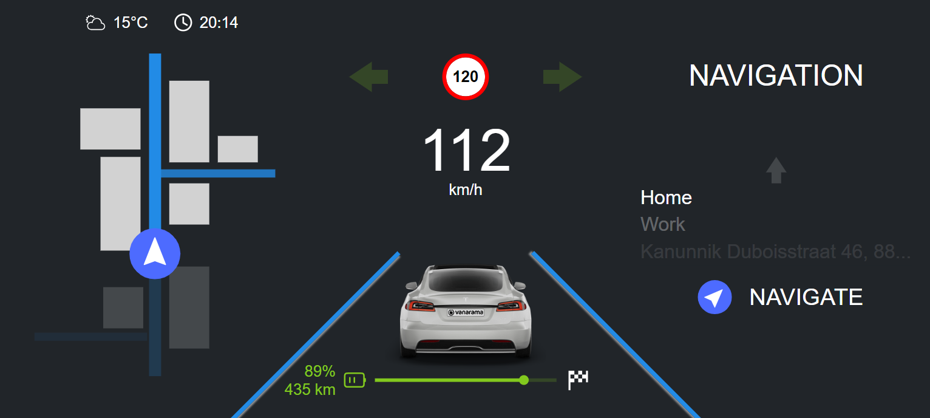
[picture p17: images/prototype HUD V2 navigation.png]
  
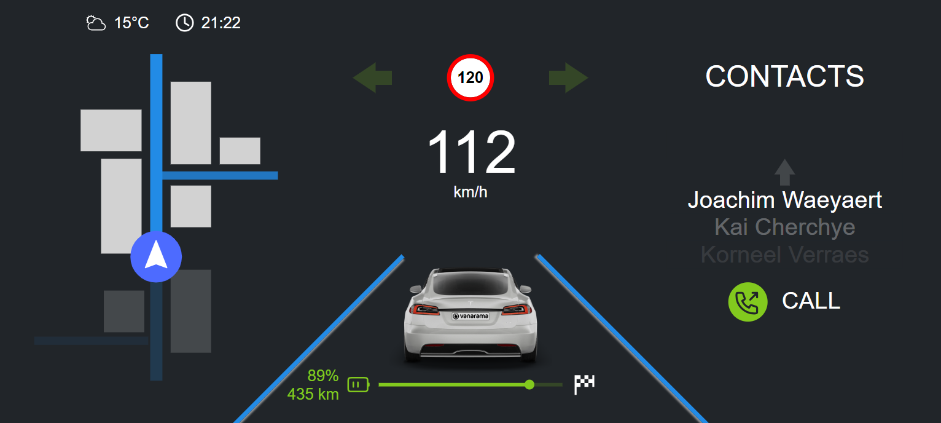
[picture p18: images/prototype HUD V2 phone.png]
  
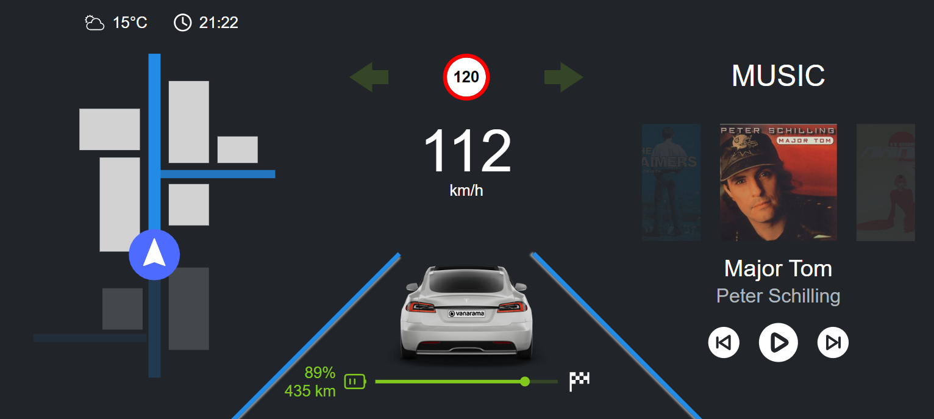
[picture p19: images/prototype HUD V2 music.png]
  
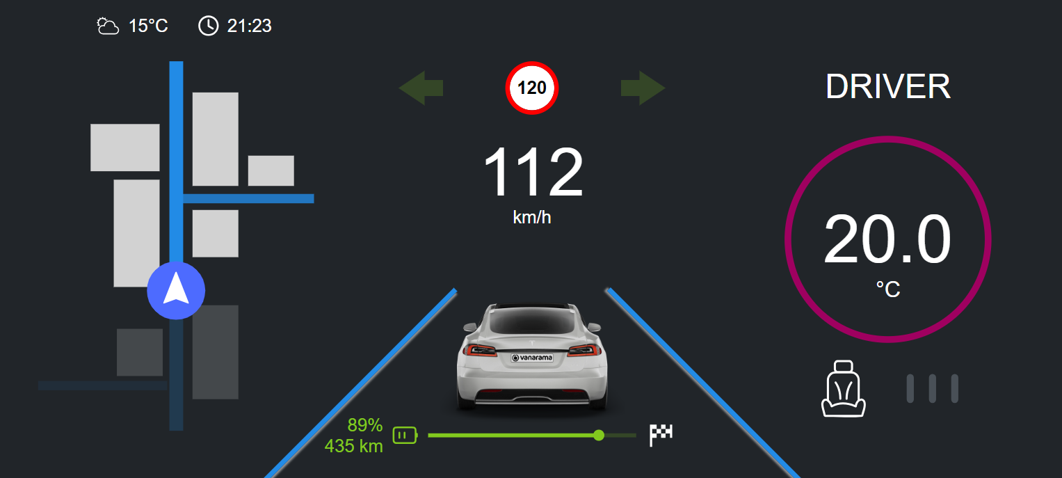
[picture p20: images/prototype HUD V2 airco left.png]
  
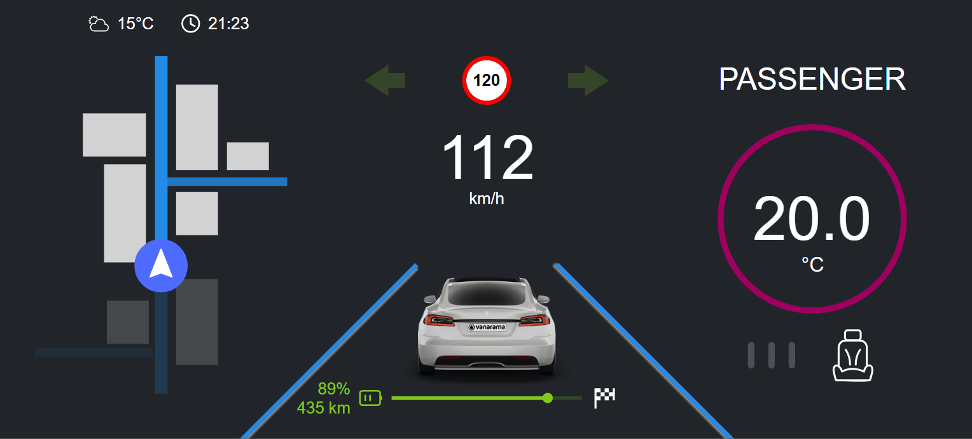
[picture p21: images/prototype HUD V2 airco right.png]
  
</p>

Elk van de 5 functies kan bediend worden door zowel te draaien en/of te klikken met de _dial_. Onderstaande tabel en gif geven een overzicht van de interacties.

||Navigation|Contacts|Music|Climate Control Driver|Climate Control Passenger|
|---:|:---:|:---:|:---:|:---:|:---:|
|draaien|bestemming selecteren|contact selecteren|nummer selecteren|temperatuur instellen|temperatuur instellen|
|klikken|bestemming bevestigen|bellen / ophangen|spelen / pauzeren|stand zetelverwarming wijzigen|stand zetelverwarming wijzigen|

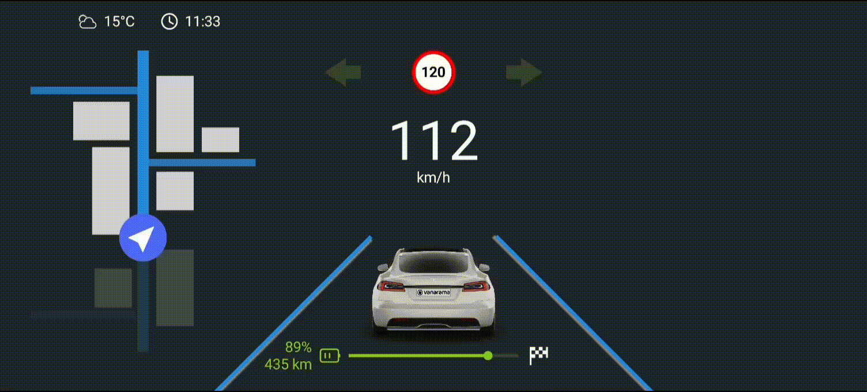
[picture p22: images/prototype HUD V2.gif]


Alle bovengenoemde onderdelen vormden samen een uitgebreid en interactief prototype waarmee we de testen in een reële context konden afnemen. Opdat de focus volledig naar het product zou kunnen gaan, testten we in een elektrische auto waarmee we de baan optrokken. We zijn ons ervan bewust dat dit een geavanceerd prototype is, toch vinden we dat dit prototype een absolute meerwaarde is. We kunnen van onszelf zeggen dat we goed overweg kunnen met het programmeren en de nodige software, zo waren we niet langer dan nodig bezig met het maken ervan. Alles werd gemaakt met het oog op snelle aanpassingen in de code of in de interface. Dit prototype zorgde ervoor dat we de validiteit van onze gebruikerstesten konden verhogen.

## Develop 2: Human Mind (N=7)
Het eindpunt van deze tweede ontwikkelingsfase is een geoptimaliseerd ontwerp, waarvan we aan de hand van een _expert review_ en _usability_ testen kunnen aantonen welke optimalisaties we hebben aangebracht.

### Doelstellingen
- Bekomen van een definitief ontwerp van het interactief prototype.
- Een efficiënte interface hebben.
-	Een effectieve interface hebben.
-	Een veilige interface hebben.
-	Een nuttige interface hebben.
-	Een eenvoudige interface hebben.
-	Een onthoudbare interactie hebben.

### Materiaal & methoden

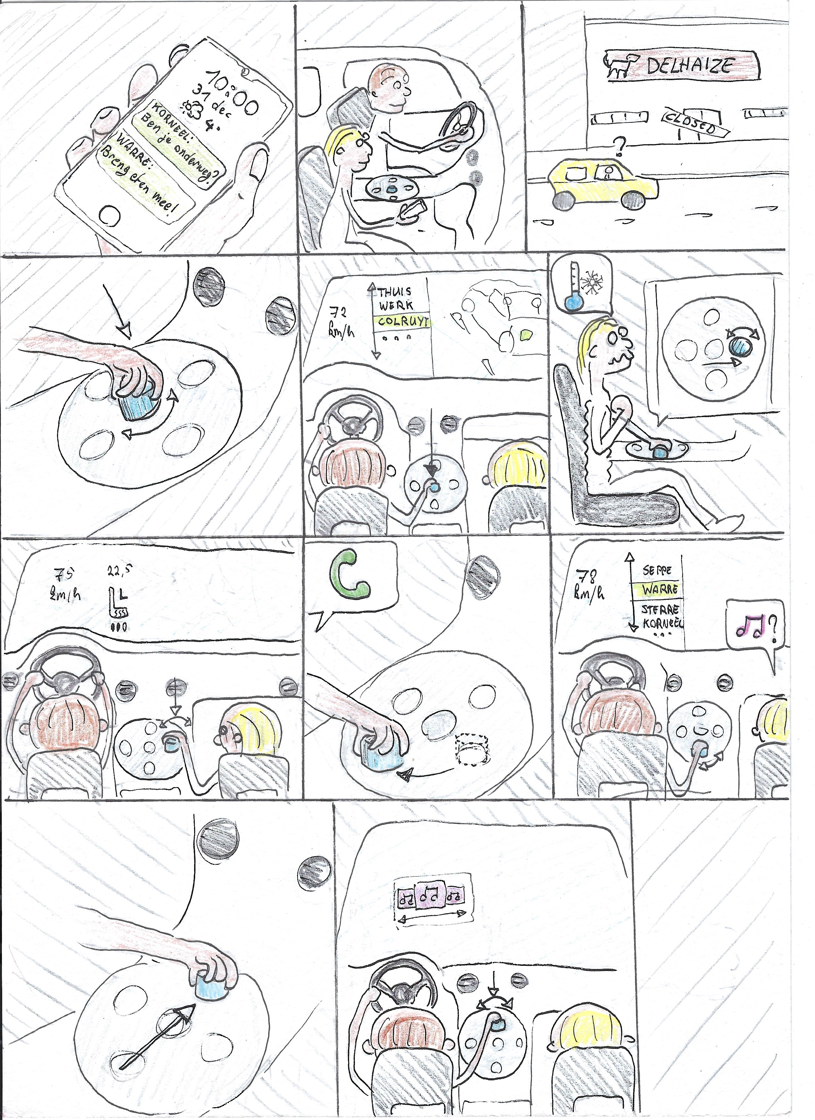
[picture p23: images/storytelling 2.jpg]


Voor de _expert review_ stelden we ons interactief prototype op. Na een korte briefing over het project en de verwachtingen werkten de experts eerst apart om elkaar niet te beïnvloeden. In een eerste ronde maakten ze kennis met het prototype om zich in te leven. In de tweede ronde richtten ze zich op specifieke features volgens de _heuristic evaluation sheet_. Na afloop bespraken we samen de pijnpunten.

Voor de _usability_ test startten we opnieuw met een korte introductie van het project om de testpersonen context te geven. De test bestond uit verschillende fases: eerste kennismaking met het prototype, daarna bediening van de functies, en vervolgens een rit. Om een zo goed mogelijke ecologische validiteit te behalen, namen we de gebruiker mee in een verhaal (zie _storytelling_). Tijdens de rit moesten gebruikers specifieke acties uitvoeren. Na de rit volgde een nabespreking en de introductie van ons nieuw concept, een losstaand controlepaneel (zie verder), om naar hun gevoel en bedenkingen te peilen. Alle inzichten en opmerkingen werden vastgelegd in een _participant form_.

### Resultaten
#### Expert review (N=2)
Uit de expert review bleek dat ons HUD nog niet duidelijk genoeg is. Er was verwarring over de grootte, helderheid, transparantie en icoontjes. De analyse gebeurt volgens de 7 vooropgestelde heuristieken:
- Minimalistisch ontwerp: Elementen zoals contacten waren moeilijk leesbaar.
- Duidelijke visuele hiërarchie: De auto op het HUD stond te prominent in beeld.
- Directe feedback: Er mist auditieve feedback.
- Gebruik van contrast en leesbaarheid: De bruikbaarheid van het HUD bij verschillende lichtomstandigheden werd betwijfeld. Echter, ervaring met benchmark HUD's leert dat dit geen probleem zou moeten zijn.
- Focus op gebruiksgemak: Het scrollen door de muziek was niet intuïtief.
- Contextuele feedback en instructies: Er ontbreekt audio- of vibratiefeedback. Er mist een synchronisatiefunctie bij de temperatuurregeling.
- Match tussen systeem en echte wereld: Geen opmerkingen.

<p align="center">
  
  
</p>

#### Usability test (N=5)
Op basis van opnames, directe feedback en formulieren kunnen we diepgaand analyseren. Bestuurders raakten soms afgeleid omdat het een prototype was. Het is beter om vooraf te melden dat de techniek kan falen en dat wij dat tijdens de test oplossen, zodat zij zich hier niet door laten afleiden.

We begonnen met een verificatie van vorige tests over posities en functies. Sommige testpersonen wilden de temperatuur van bestuurder en passagier aan de uiterste posities zien. Eén persoon vond de navigatie storend in beeld; een L-vormige indeling zou beter zijn. Relatieve posities kunnen naar voorkeur worden aangepast (software), maar absolute posities blijven hetzelfde (hardware). Bij de eerste testrun ontdekten de meeste gebruikers de zetelverwarming niet. Een persoon vond deze functie overbodig omdat die maar een paar maanden per jaar wordt gebruikt. Een logische startpositie zou de navigatie zijn. Eén testpersoon wilde meer voorgelezen opties, terwijl anderen de voorgelezen menu’s storend vonden.

We merkten dat het op enkele momenten lastig was om een bepaald adres, telefoonnummer, muzieknummer of temperatuur te selecteren. De _dial_ was te gevoelig.

> "De afleiding met mijn huidige auto is beduidend minder. Het gebruik van Ctrl-Wheely is slechts een gewoontekwestie, na een paar ritten is het systeem zeker een meerwaarde. De magneten zijn zeer handig."

De _dial_ hoeft niet groot te zijn; een kleinere maat past bijvoorbeeld in je broekzak en kan dienen als autosleutel. Een grote _dial_ straalt echter meer sympathie uit. De _dial_ kan ook gebruikt worden om geluidsverdeling te regelen door verschuiving rond een magnetisch middelpunt, en om muziek te bedienen met klikken en dubbelklikken. Door de verkeerde _affordance_ (conische vorm) hadden veel gebruikers de neiging de _dial_ op te heffen.

Het tweede concept van een losstaand controlepaneel werd positief ontvangen. Het voelde logischer aan dan een _dial_ op het scherm. Testpersonen vonden dat het controlepaneel verticaal in de middenconsole geïntegreerd mag worden, maar wilden hun bekerhouders niet verliezen. Een cirkelvormige positie van het controlepaneel werd als intuïtiever ervaren. De meeste testpersonen vonden dat het scherm kleiner mag zijn, gemiddeld met een factor 2/3.

<p align="center">
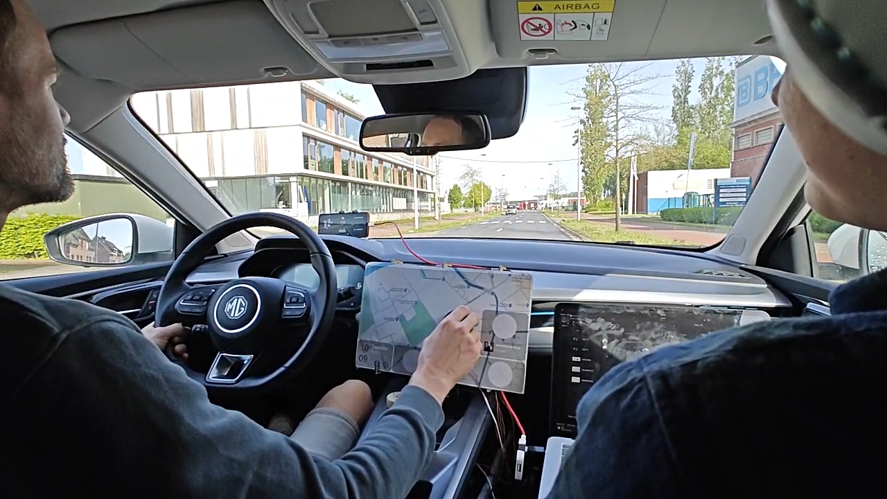
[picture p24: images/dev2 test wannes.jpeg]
  
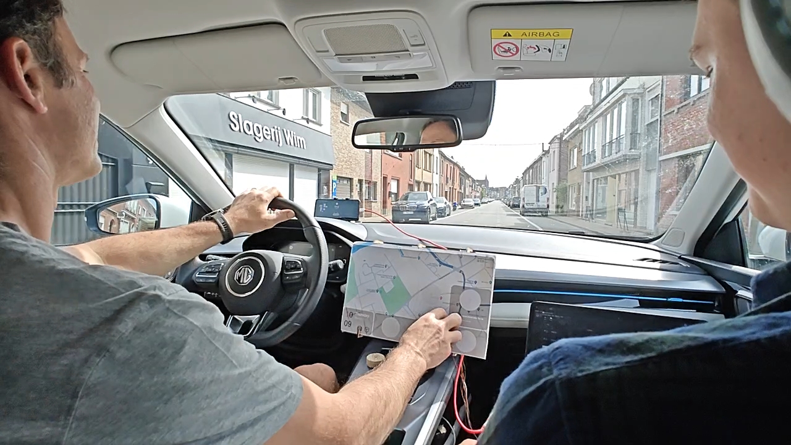
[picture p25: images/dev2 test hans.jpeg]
  
</p>

### Conclusies & implicaties
Om een betere context te bieden aan de testpersoon maken we een visualisatie van het HUD in de auto. We vermelden hierbij de nodige extra uitleg. Ook moeten we vermelden welke slimme functies de auto al heeft en wat niet meer handmatig geregeld hoeft te worden.

De draairichting en de gevoeligheid bij het scrollen door de lijsten kan softwarematig worden aangepast. In de interface wordt er een blijvende pop-up geïntegreerd wanneer je aan het bellen bent en door andere menu’s aan het scrollen bent. Ook de muziek die afspeelt blijft continu weergegeven. Al deze zaken zorgen voor een vrij druk HUD. Daarom maakten we een opsplitsing van welke informatie in het HUD wordt weergegeven en welke in het dashboard achter het stuur. De onderstaande figuur illustreert dit.

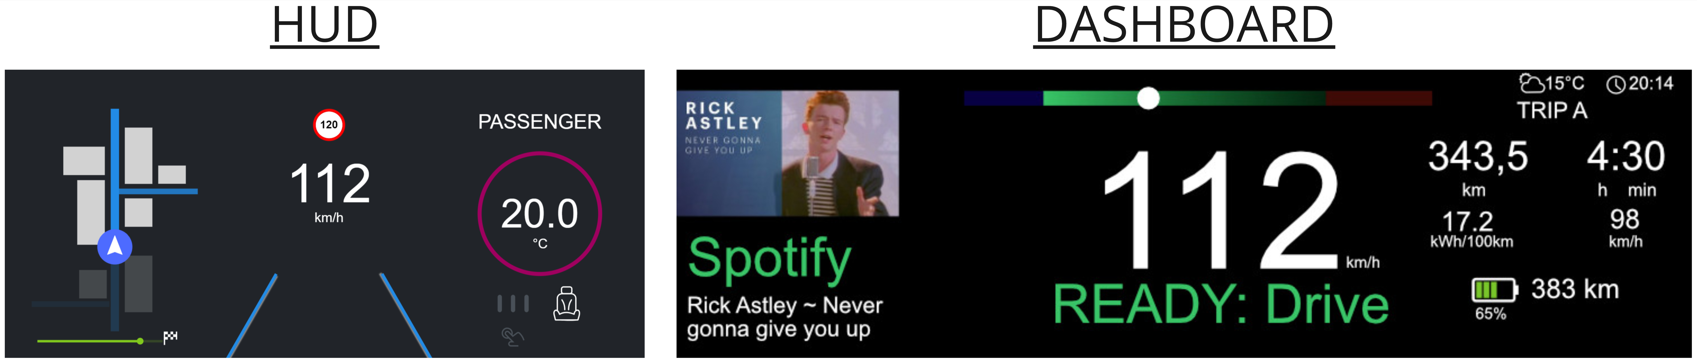
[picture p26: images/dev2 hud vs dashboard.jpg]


Om de afleiding - veroorzaakt door het HUD - verder te beperken, voegen we ook een stem toe die aangeeft in welk menu je je bevindt. Een haptische motor in de _dial_ zorgt voor de nodige tactiele feedback.

Ten slotte wordt er gezocht naar een mogelijkheid om de temperatuur van bestuurder en passagier te synchroniseren.

Na het _industry consult_ kwamen we op een punt waar we ons concept helemaal konden omgooien. Een enge stap, maar deze werd ook aangemoedigd door onze testgebruikers. In plaats van de _dial_ op het touchscreen te plaatsen zal deze nu bediend worden op een controlepaneel dat in de middenconsole verwerkt zit, met behoud van de drankenhouders. Verder zullen de posities ook niet meer lineair uitgelijnd worden, maar cirkelvormig. Dit creëert een centrale positie (bijvoorbeeld de navigatie). Links en rechts worden respectievelijk de temperatuur voor de bestuurder en de passagier. Boven en onder worden ingevuld door de telefoon en de muziek. Dit is veel intuïtiever en eenvoudiger blind te bedienen. Dit nieuwe concept wordt duidelijk in het volgende deel.

Het scherm wordt terug het oorspronkelijke scherm zoals reeds in de testauto aanwezig. Daarnaast is er de mogelijkheid om de _dial_ kleiner te maken tot een broekzakformaat. Op die manier zou de _dial_ ook als autosleutel gebruikt kunnen worden. Door de _dial_ / autosleutel op de centrale positie te plaatsen kan de auto gestart worden. Dit idee vloeide voort uit de _usability_ test waarbij de _dial_ nog op het touchscreen bediend werd. Echter weten we niet of dit ook nog van toepassing zal zijn bij ons nieuw concept, dit zal bevraagd worden in een volgende gebruikerstest.

De uitdaging op dit _pivot point_ zit hem in het maken van een nieuw controlepaneel dat toch nog steeds modern en innovatief oogt. In de laatste testen gaan we deze laatste inzichten al dan niet verifiëren bij een nieuwe groep gebruikers.

> [!IMPORTANT]
> Design Requirements:
> - D1.5 Het product beschikt over auditieve feedback bij het veranderen van menu.
> - D1.6 Het product laat toe de auditieve feedback uit te schakelen of aan te passen.
> - D1.7 Het product laat toe de temperatuur van zowel de passagier als de bestuurder in één handeling te synchroniseren en te regelen.
> - D1.8 Het product oogt modern en innovatief.
> - D2.5 De _dial_ laat toe de draairichting om te keren.
> - D2.6 De _dial_ geeft niet de intentie opgeheven te kunnen worden.
> - D2.7 De _dial_ kan op verschillende manieren bediend worden.
> - D3.6 Het touchscreen is kleiner dan 10 inch.
> - D4.1 Het HUD toont een blijvend icoon tijdens het bellen bij het veranderen van menu.
> - D4.2 Het HUD toont een blijvend icoon van de muziek bij het veranderen van menu.
> - D4.3 Het HUD kan de helderheid automatisch laten aanpassen aan de lichtintensiteit buiten.
> - D4.4 Het HUD beschikt over augmented reality.
> - D4.5 Het HUD is groter dan een gemiddeld smartphonescherm (6,5 inch).
> - D4.6 Het HUD toont duidelijk de mogelijkheid van de zetelverwarming.
> - D5.1 Het controlepaneel heeft een intuïtieve positieverdeling.
> - D5.2 Het controlepaneel neemt niet de plaats in van de bestaande bekerhouders.

## Prototype
Bij dit prototype gooiden we ons hele concept om. Het touchscreen maakte plaats voor een controlepaneel in de middenconsole. De functionaliteiten bleven dezelfde.

### Controlepaneel
Het controlepaneel is cirkelvormig en bevat vijf posities. Dit werd gemaakt met de lasercutter. Het principe van de _snapping points_ door middel van magneten, rosse munten en magneetsensoren bleef hetzelfde. Er werden ook enkele tussenstukken gemaakt om dit controlepaneel in de testauto te integreren. 

<p align="center">
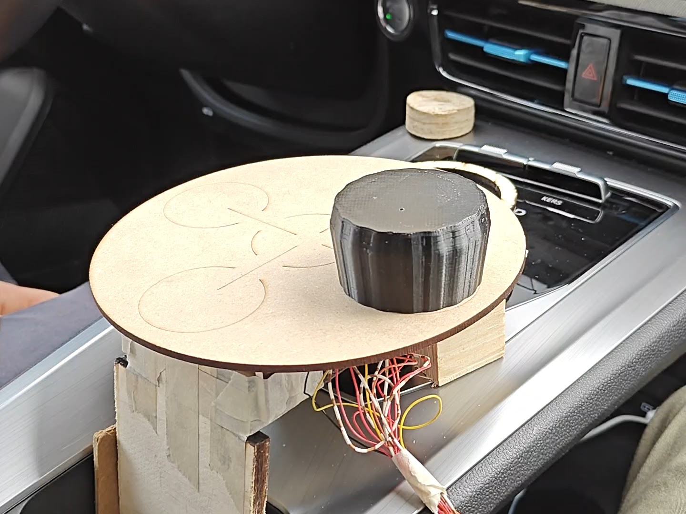
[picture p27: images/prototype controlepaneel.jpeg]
  
  
</p>

### Dial
De gevoeligheid van de _dial_ werd softwarematig verminderd door een extra variabele 'grens' toe te voegen. Alleen het gedeelte dat de rotatie van de encoder uitleest, werd aangepast. Verder zijn er geen wijzigingen aangebracht aan de vorm, grootte, hardware...

```py
if (encoderState != encoderLastState) {
  if (digitalRead(encoderBPin) != encoderState) {
    direction = 0;
    if (direction == 0 && lastDirection == 0) {
      teller0 += 1;
      if (teller0 == grens) {
        teller0 = 0;
        teller1 = 0;
        Serial.println("dir0");
        central.writeValue((byte)0x02);
        direction = 1;
      }
    }
    lastDirection = direction;
  } else {
    direction = 1;
    if (direction == 1 && lastDirection == 1) {
      teller1 += 1;
      if (teller1 == grens) {
        teller1 = 0;
        teller0 = 0;
        Serial.println("dir1");
        central.writeValue((byte)0x03);
        direction = 0;
      }
    }
    lastDirection = direction;
  }
}
encoderLastState = encoderState;
```

### HUD
De interface van het HUD werd verder geoptimaliseerd. Mede om de gevoeligheid te verkleinen, verandert de temperatuur per gehele graad in plaats van per halve graad. Ook werd een extra icoontje toegevoegd om aan te geven dat de stand van de zetelverwarming aangepast kan worden door op de _dial_ te klikken. De prominent aanwezige auto, de tijd, de datum en het rijbereik werden verplaatst naar het dashboard achter het stuur.

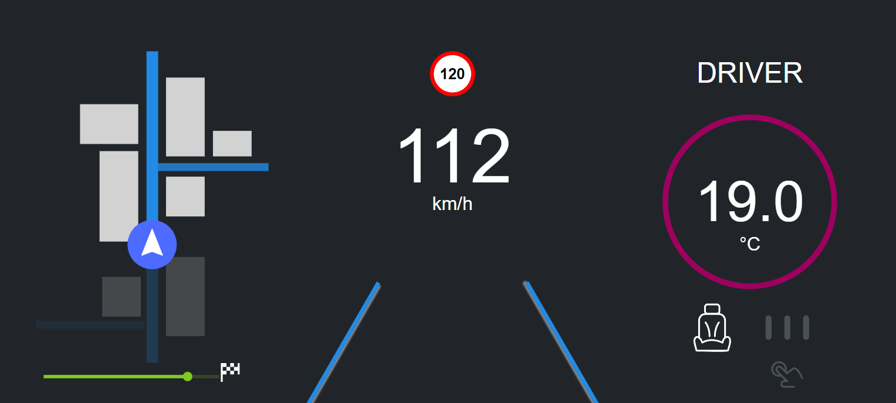
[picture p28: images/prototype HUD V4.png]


Ook al gooiden we hier ons concept volledig om, toch slaagden we erin ons prototype zeer snel om te bouwen tot ons nieuw concept. De softwareveranderingen zijn zeer beperkt. Qua hardware was het enkel een kwestie van overplaatsen. Met minieme veranderingen konden we dus opnieuw naar de gebruiker trekken. 

### Overzicht
Tijdens ons parcour hebben we heel wat keuzes moeten overwegen. Om alles overzichtelijk te houden hebben we gaandeweg een morfologische kaart opgesteld. Hieronder is een overzicht waarop zowel het oude als het nieuwe concept te zien is.

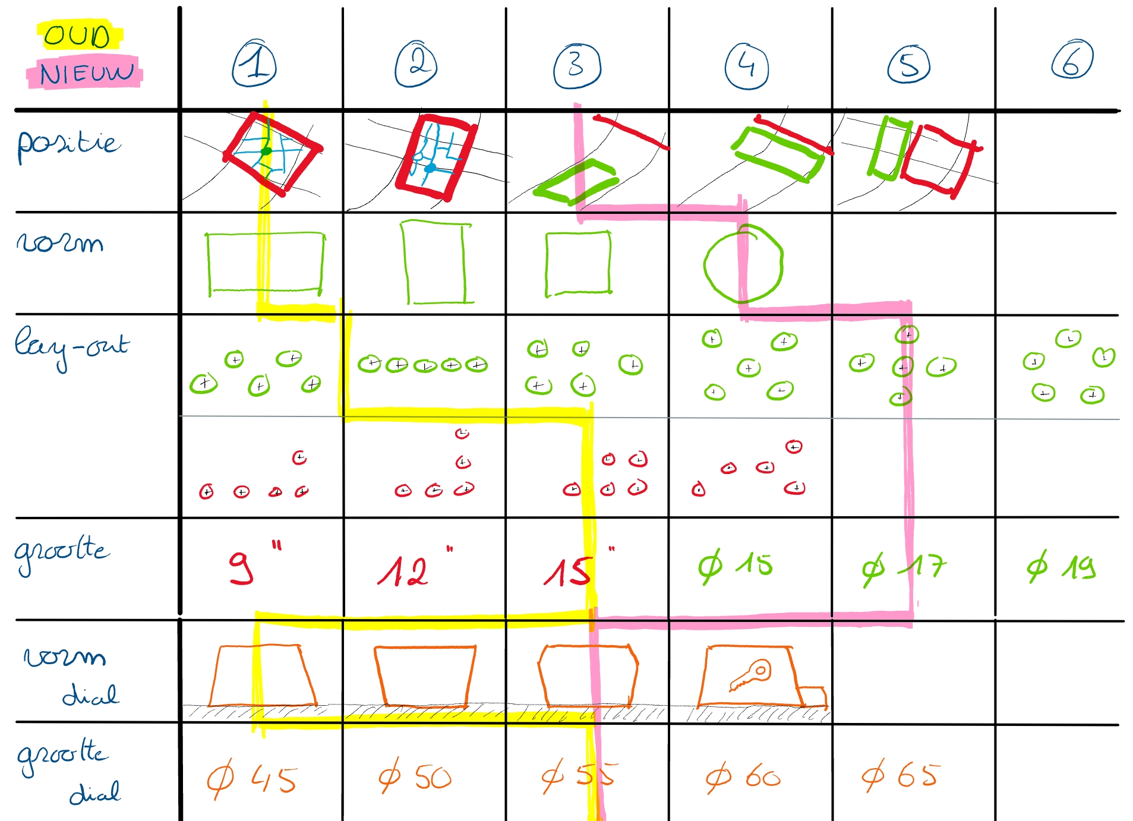
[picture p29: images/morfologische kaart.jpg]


## Develop 3: Human Senses (N=8)
Het eindpunt van deze derde ontwikkelingsfase is een geoptimaliseerd ontwerp, waarvan we aan de hand van een hiërarchise taakanalyse en gebruikerstesten kunnen aantonen welke optimalisaties we hebben aangebracht.

### Doelstellingen
- De kwaliteit van het controlepaneel achterhalen.
- Bevestiging of verwerping van designbeslissingen op basis van de vorige test.
- Het hebben van een definitief prototype van Ctrl-Wheely.
- Kwantificatie van de afleiding tijdens het rijden.

### Materiaal & methoden
We trokken voor het eerst naar de gebruiker met een nieuw prototype: ons controlepaneel. De opstelling blijft zo goed als identiek aan de vorige test. Uit de vorige testen leerden we dat de besturing van de _dial_ soms te gevoelig en niet consistent was. Hiervoor werd de _dial_ aangepast zoals hierboven uitgelegd wordt. Bij deze test richten we ons op de sensoriële feedback, vandaar dat we de _dial_ voorzien van een betere sensoriële werking. Voor het opstellen van een hiërarchische taakanalyse pikten we er één specifiek voorbeeld uit: de _climate control_.

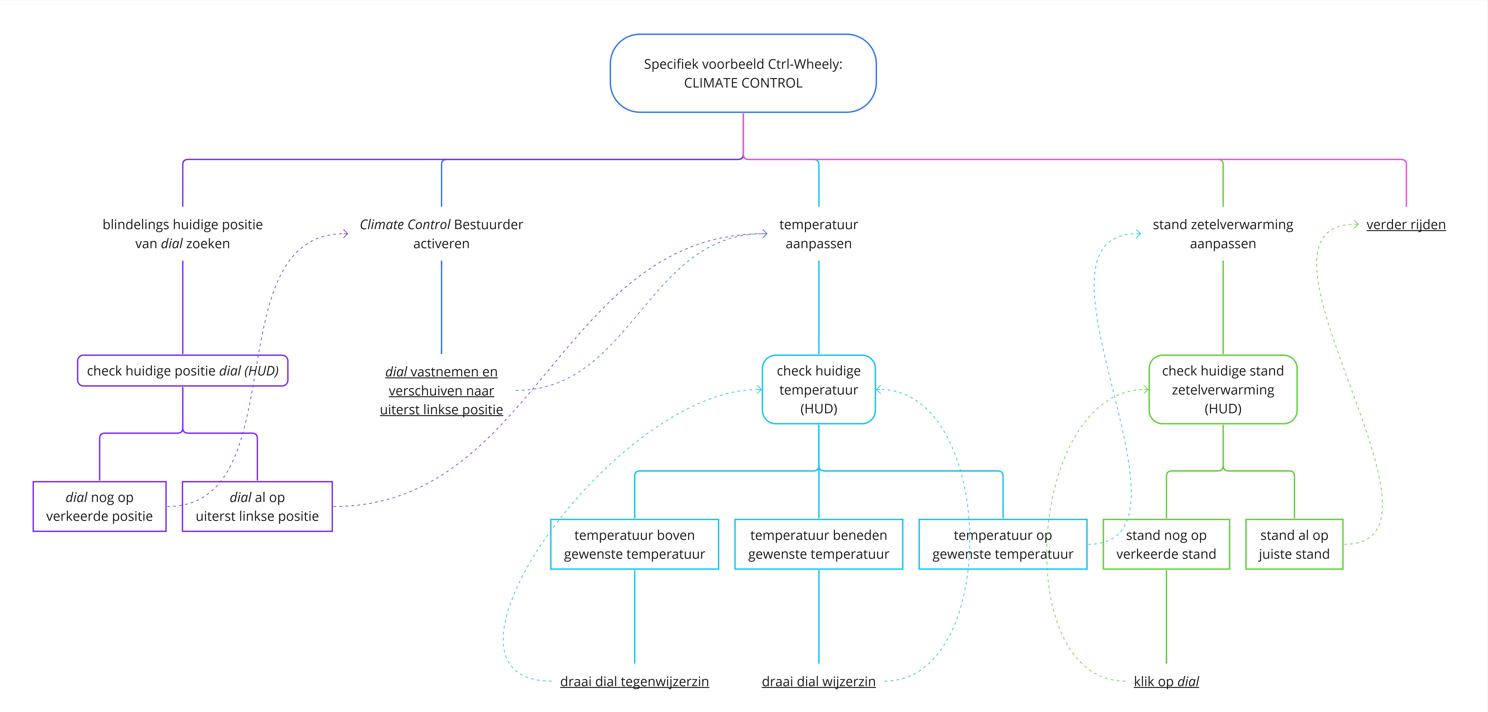
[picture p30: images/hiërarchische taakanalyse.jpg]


Als eerste opdracht mochten de testpersonen Ctrl-Wheely ontdekken in al zijn mogelijkheden. Nadat alle functies ontdekt waren en de persoon zelf aangaf dat alles blindelings en veilig bediend kon worden, konden we vertrekken voor een rit. Tijdens de rit moesten de gebruikers specifieke acties uitvoeren volgens een vooropgestelde context. Na de rit volgde een nabespreking en een introductie tot het idee om de _dial_ ook te gebruiken als autosleutel. Daarna volgde voor de gewillige gebruikers ook een risicoperceptietest. Hiervoor werd een laptop op de motorkap geplaatst voor de ogen van de testpersoon. Ze kregen twaalf fragmenten te zien. Telkens zes fragmenten waarin ze opdrachten moesten voltooien via de interface (touchscreen) van de testwagen, en zes andere fragmenten waarbij ze opdrachten moesten voltooien met Ctrl-Wheely. Aan de hand van deze test wilden we de mate van afleiding kwantificeren, te vergelijken met een andere benchmark. Alle inzichten en opmerkingen werden vastgelegd in een _participant form_.

### Resultaten
Op basis van opnames, directe feedback en formulieren kunnen we een diepgaande analyse uitvoeren.

Net als in de vorige test werd de zetelverwarming, ondanks een toegevoegd symbool, door het merendeel niet ontdekt. Het gaat meestal over gebruikers die in hun huidige wagen geen zetelverwarming hebben en er daarom niet aan denken.

Uit de vorige test (nog met touchscreen) bleek dat mensen vaak de neiging hadden om de _dial_ op te heffen. Wegens praktische beperkingen van het prototype hadden we geen aangepaste _dial_ kunnen voorzien (in het sleutelprototype zit dit wel verwerkt). Doordat het controlepaneel nu horizontaal ligt, was echter niemand geneigd de _dial_ op te heffen. We kunnen dus stellen dat het ontwerp van de _dial_ dan toch goed zit. Zowat iedereen vermeldde dat de huidige _dial_ zeer goed in de hand ligt. De navigatie als startpositie en de temperatuur links & rechts werden als zeer intuïtief bevonden. Iedereen was grote fan van het cirkelvormige controlepaneel en de bijhorende _snapping points_.

> "Op deze manier kan je veel sneller door belangrijke menu’s scrollen in tegenstelling tot mijn BMW waar ook een draaiknop in de middenconsole zit."

Het controlepaneel staat op een zeer comfortabele positie, dat werd aangehaald door testpersonen van verschillende groottes. Er werd aan de gebruikers opnieuw gevraagd welke grootte van touchscreen ze voor ogen hadden, nu de _dial_ niet meer op het scherm bediend wordt. De gebruikers gaven aan dat ze toch graag een groot touchscreen hebben, ook al dient deze enkel voor tijdens het stilstaan en als kaartweergave.

Iemand gaf aan dat het noodzakelijk is om in het HUD altijd te kunnen zien in welk menu je zit, een kleine indicatie d.m.v. een icoontje volstaat. De vorm van het controlepaneel zou in het klein kunnen weergegeven worden op het HUD, met daarop de huidige positie van de _dial_. Zo zie je niet enkel in welk menu je zit, maar kan je ook zien hoe je naar een ander menu kan _snappen_.

Bij het bevragen van het idee om de _dial_ te gebruiken als autosleutel was het antwoord vaak dubbel. Een kleinere dial ziet er alvast moderner uit, maar is moeilijker te bedienen dan de grotere _dial_ zoals tijdens het testen. Ten tweede wordt de handige functie van een keyless sleutel dan tenietgedaan. De sleutel kan je, zoals de meeste gebruikers doen, niet gewoon in de broekzak of handtas laten zitten. Je moet ze telkens uithalen en terug meenemen.

De risicoperceptietest verliep wat stroever dan de rijtest. Zowel de testpersoon als wijzelf gaven aan dat bepaalde factoren de test te veel beïnvloeden:
-	Een risicoperceptietest is in elk geval al geen gemakkelijke test. Je moet dit met volle concentratie en in volledige stilte kunnen afleggen om een goed resultaat te halen. Daarnaast benoemden de testpersonen verschillende keren dat het erg onduidelijke en donkere fragmenten waren. 
-	Bij het prototype van ons concept moet je nog steeds op een scherm zaken aflezen. De informatie wordt niet op de weg (of op het fragment) geprojecteerd, zoals dat in het eindproduct wel het geval zou zijn.
-	Veel hangt af van het moment waarop je de opdracht aan de testpersoon geeft. Fragmenten duren gemiddeld zo’n 30 seconden. Een opdracht geven duurt nog geen 5 seconden. Als mensen de opdracht in het begin van het fragment krijgen en de bevraagde gebeurtenis pas op het einde plaatsvindt, dan scoor je goed aangezien de opdracht al uitgevoerd werd en de volle concentratie terug op het fragment lag. Omgekeerd kan het ook zijn dat de opdracht net op het moment valt dat er iets gebeurt in het fragment.
-	Als laatste moeten we eerlijk zijn en toegeven dat ook bij ons concept sprake is van afleiding.

<p align="center">
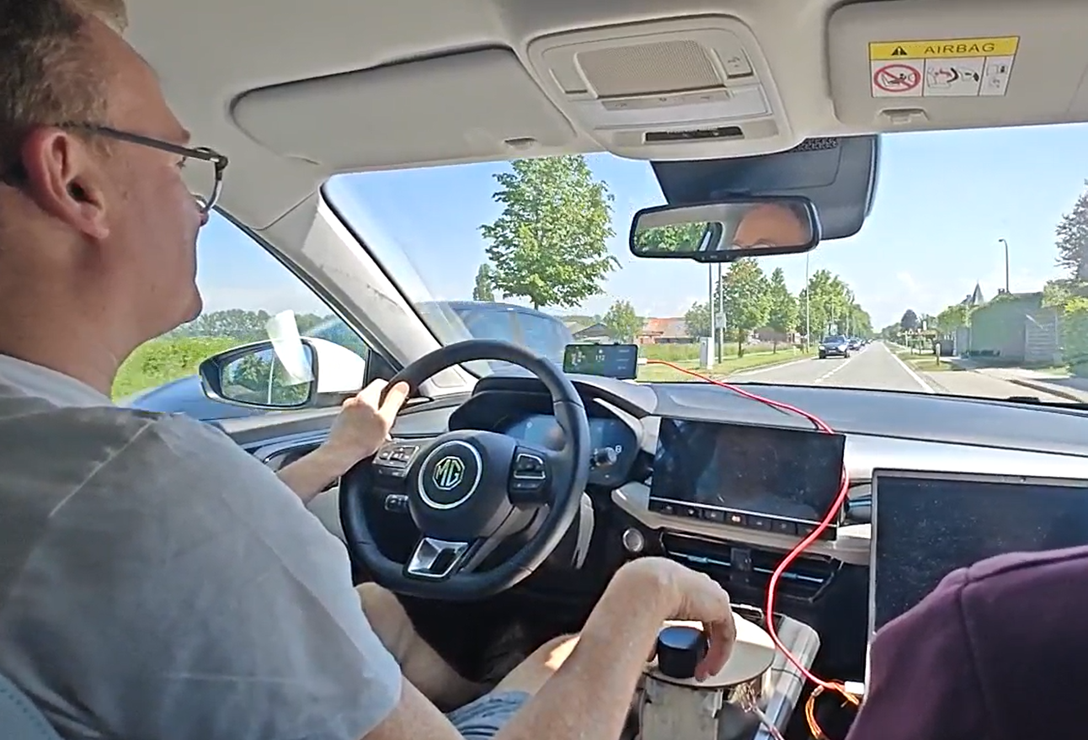
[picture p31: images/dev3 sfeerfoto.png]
  
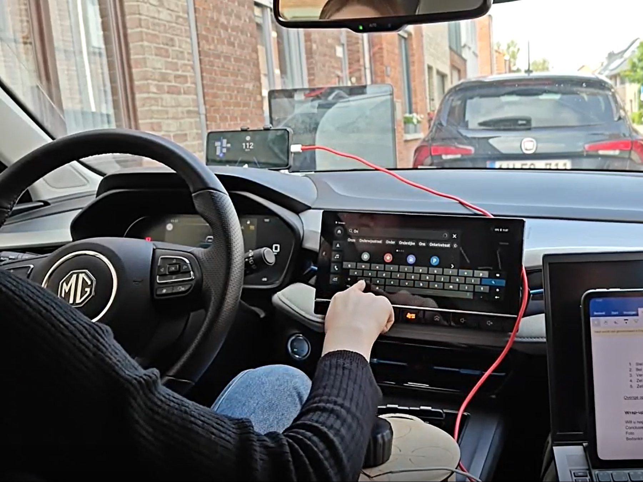
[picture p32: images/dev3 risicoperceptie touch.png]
  
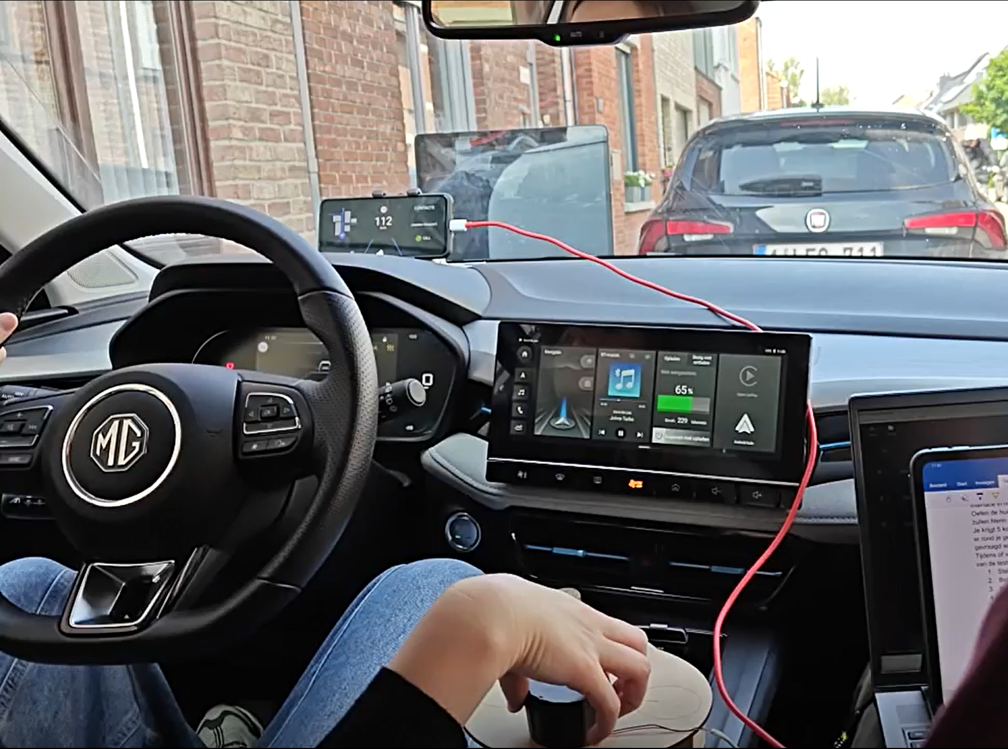
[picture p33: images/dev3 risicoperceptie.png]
  
</p>

### Conclusies & implicaties
Ondanks dat we met dit concept geen antropometrische testen hebben kunnen doen, kunnen we wellicht toch stellen dat dit concept ook op dat vlak goed zit. Mensen willen nog steeds een touchscreen die groter is dan het 10 inch grote interface van de testwagen en kleiner dan een 17 inch Tesla-scherm. 
De _dial_ zal om verschillende redenen niet gebruikt worden als autosleutel.
Aan het HUD wordt een icoontje toegevoegd om de gebruiker steeds een indicatie te geven in welk menu je zit en hoe je naar andere menu’s kan navigeren.

<p align="center">
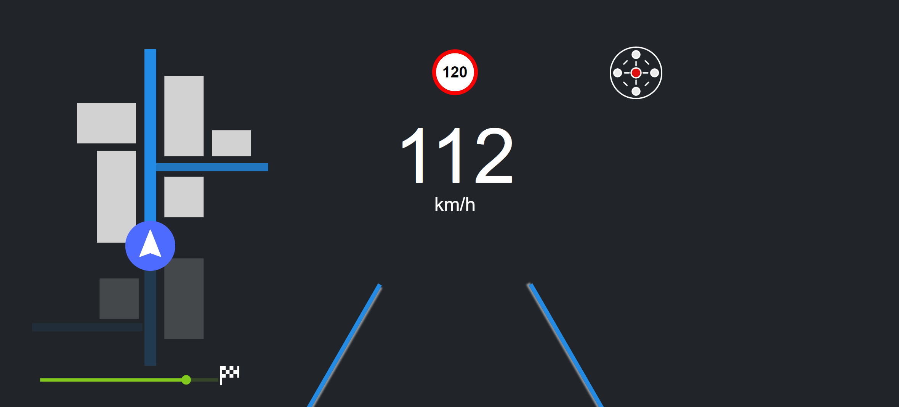
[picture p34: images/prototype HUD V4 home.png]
  
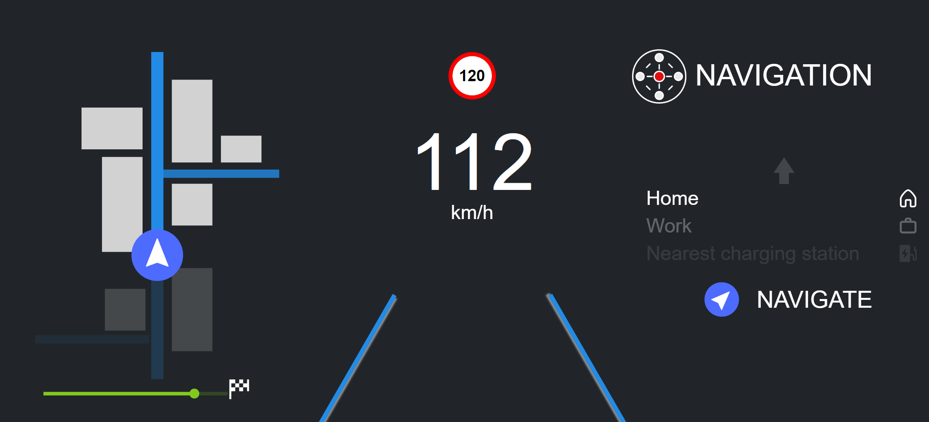
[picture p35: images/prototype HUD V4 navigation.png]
  
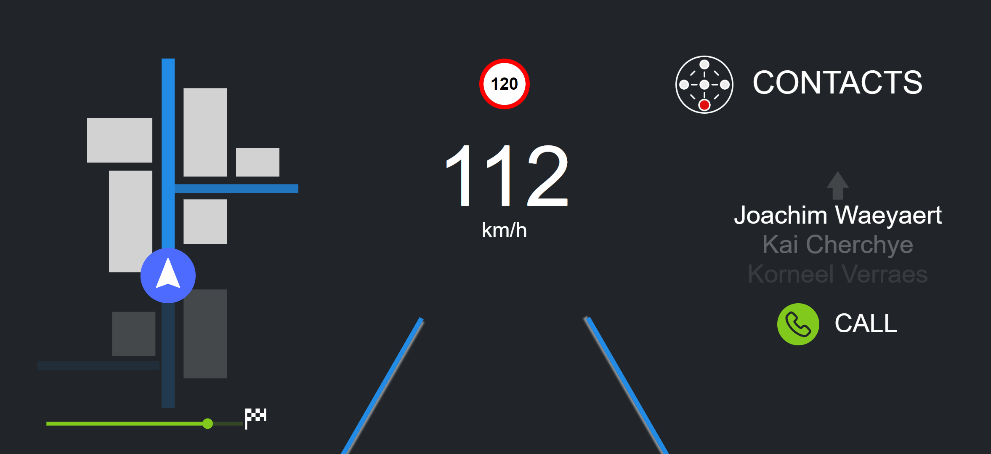
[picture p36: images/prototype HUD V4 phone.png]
  
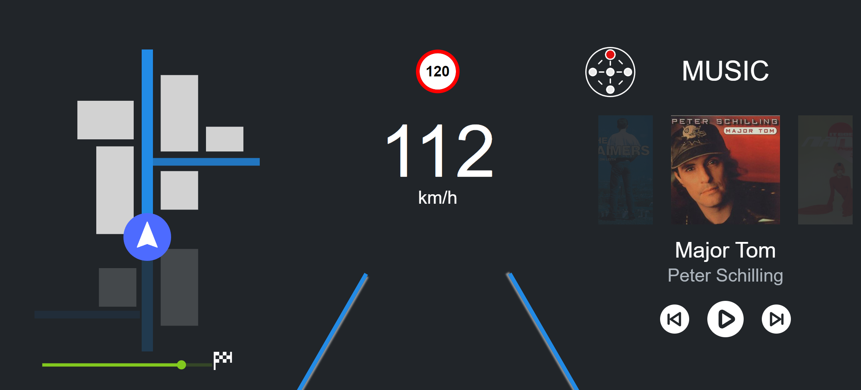
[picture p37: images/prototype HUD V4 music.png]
  
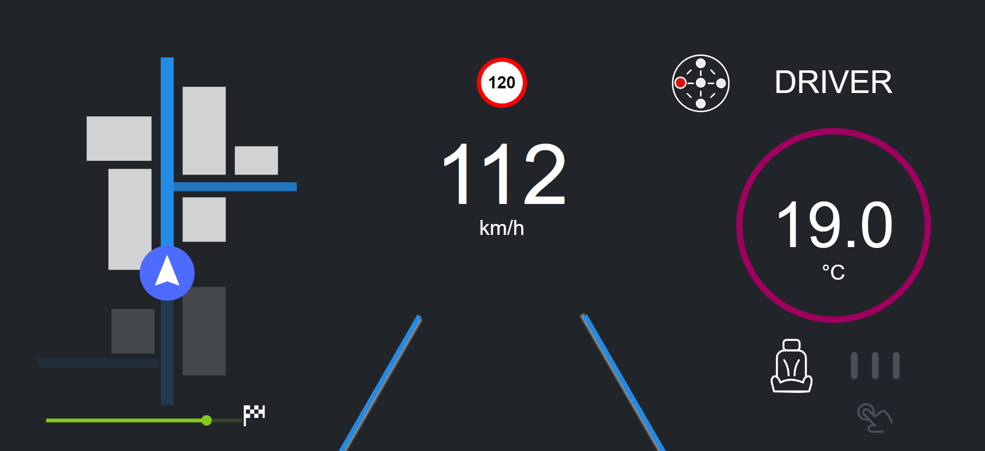
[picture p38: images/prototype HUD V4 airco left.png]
  
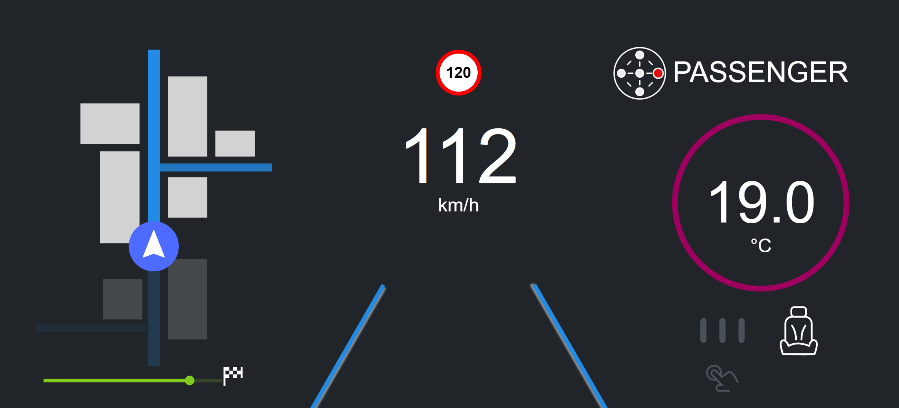
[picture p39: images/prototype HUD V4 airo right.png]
  
</p>

Omwille van voorgenoemde redenen hebben we besloten de scores van de risicoperceptietest te verwerpen. De resultaten zijn afhankelijk van externe factoren en dus geen goede maatstaaf om de afleiding te kwantificeren. De risicoperceptietest werd wel vastgelegd op beeld. Op de beelden is te zien dat de bediening met Ctrl-Wheely significant sneller uitgevoerd wordt dan met het touchinterface. Dit werd mondeling bevestigd door de testpersonen. Om dit objectief te analyseren zouden we het verschil in tijd kunnen timen. Of nog beter zou zijn om gebruik te maken van een _eye-tracking_ bril om de afleiding te kwantificeren. Door tijdsgebrek zijn we hier echter niet in geslaagd.

We blikken tevreden terug op de laatste test. We kregen vooral bevestiging over de meerwaarde van ons concept. 

> [!IMPORTANT]
> Design Requirements:
> - D2.8 De _dial_ kan enkel binnen de auto gebruikt worden.
> - D3.7 Het touchscreen is tussen de 10 en 17 inch.
> - D4.7 Het HUD toont te allen tijde op welke positie de dial staat.

## Overzicht Design Requirements
|ID|Design Requirement|Source|Date|
|:---|:---|:---|:---|
|**Groep 1**|**Algemeen**|
|1.1|Het product laat toe functies te bedienen zonder dat de ogen van de baan afwijken.|Meeting Granstudio|19/10/2023|
|1.2|Het product laat toe zes functies veilig te bedienen tijdens het rijden. |Interface user test|02/01/2024|
|1.3|Het product is voor 95% van de mensen op elke mogelijke positie comfortabel toegankelijk.|Human body user test|05/03/2024|
|1.4|Het product laat toe het volume met een aparte knop te bedienen.|Human body user test|05/03/2024|
|1.5|Het product beschikt over auditieve feedback bij het veranderen van menu.|Expert Review|22/04/2024|
|1.6|Het product laat toe de auditieve feedback uit te schakelen of aan te passen.|Expert Review|22/04/2024|
|1.7|Het product laat toe de temperatuur van zowel de passagier als de bestuurder in één handeling te synchroniseren en te regelen.|Expert Review|22/04/2024|
|1.8|Het product oogt modern en innovatief.|Human mind user test|01/05/2024|
|**Groep 2**|**Dial**|
|2.1|De _dial_ geeft haptische feedback bij het bedienen van de functies.|_dial_ user test|24/12/2023|
|2.2|De _dial_ heeft een conische vorm.|_dial_ user test|24/12/2023|
|2.3|De _dial_ ligt voor 95% van de mensen goed in de hand.|_dial_ user test|24/12/2023|
|2.4|De _dial_ kan ook naast het scherm bediend worden.|Interface user test|02/01/2023|
|2.5|De _dial_ laat toe de draairichting om te keren.|Expert Review|22/04/2024|
|2.6|De _dial_ geeft niet de intentie opgeheven te kunnen worden.|Human mind user test|01/05/2024|
|2.7|De _dial_ kan op verschillende manieren bediend worden.|Human mind user test|01/05/2024|
|2.8|De _dial_ kan enkel binnen de auto gebruikt worden.| Human senses user test|19/05/2024|
|**Groep 3**|**Touchscreen (deels van toepassing)**|
|3.1|Het touchscreen laat toe de functies en hun bijhorende posities onderling te wijzigen.|Interface user test|02/01/2024|
|3.2|Het touchscreen is goed leesbaar.|Interface user test|02/01/2024|
|3.3|Het touchscreen oogt modern.|Interface user test|02/01/2024|
|3.4|Het touchscreen geeft niet de intentie met touch bediend te kunnen worden tijdens het rijden.|Human body user test|05/03/2024|
|3.5|(n.v.t.) Het touchscreen laat niet toe functies te bedienen binnen 1/4 van de linkerkant.|Human body user test|05/03/2024|
|3.6|(n.v.t.) Het touchscreen is kleiner dan 10 inch.|Human mind user test|01/05/2024|
|3.7|Het touchscreen is tussen de 10 en 17 inch.|Human senses user test|19/05/2024|
|**Groep 4**|**Head-up-display**|
|4.1|Het HUD toont een blijvend icoon tijdens het bellen bij het veranderen van menu.|Expert Review|22/04/2024|
|4.2|Het HUD toont een blijvend icoon van de muziek bij het veranderen van menu.|Expert Review|22/04/2024|
|4.3|Het HUD kan de helderheid automatisch laten aanpassen aan de lichtintensiteit buiten.|Expert Review|22/04/2024|
|4.4|Het HUD beschikt over augmented reality.|Expert Review|22/04/2024|
|4.5|Het HUD is groter dan een gemiddeld smartphonescherm (6,5 inch).|Expert Review|22/04/2024|
|4.6|Het HUD toont duidelijk de mogelijkheid van de zetelverwarming.|Human mind user test|01/05/2024|
|4.7|Het HUD toont te allen tijde op welke positie de _dial_ staat.|Human senses user test|19/05/2024|
|**Groep 5**|**Controlepaneel**|
|5.1|Het controlepaneel heeft een intuïtieve positieverdeling.|Human mind user test|01/05/2024|
|5.2|Het controlepaneel neemt niet de plaats in van de bestaande bekerhouders.|Human mind user test|01/05/2024|

## Finaal prototype
Na een jaar hard werken zijn we tot een finaal prototype gekomen: Ctrl-Wheely. Een fysieke verplaatsbare knop op een controlepaneel in de middenconsole waarmee je de verschillende functies van je auto bedient. Alles wat je aan het bedienen bent wordt weergegeven in een head-up display (HUD).

Door de intuïtieve manier van bedienen, de eenvoudige interacties en de weergave in het gezichtsveld, vormt Ctrl-Wheely de ideale oplossing voor een veilige autorit.

In de hedendaagse, moderne auto worden al heel wat functies automatisch aangestuurd. Denk hierbij aan de voor- en achterruitverwarming, ruitenwissers, lichten, airco... Deze nemen al een groot deel van de potentiële afleiding weg. Andere functies worden, omwille van diezelfde afleiding, beperkt tijdens het rijden. Er schieten dus nog een aantal functies over die de autobestuurder zelf, tijdens het rijden, in handen wil hebben (letterlijk). Dit zijn de navigatie, telefoon, muziek, temperatuur (bestuurder & passagier) en zetelverwarming (bestuurder & passagier). Dankzij Ctrl-Wheely kunnen deze allemaal op een veilige manier bediend worden.

Ctrl-Wheely is een samenhangend geheel van drie belangrijke onderdelen: de _dial_, het controlepaneel en het HUD.

### Dial
De autobestuurder kan de _dial_ verplaatsen om te kiezen welke functie hij/zij wil bedienen, aan de _dial_ draaien om binnen een menu te scrollen en op de knop drukken om te selecteren. De _dial_ ligt dankzij zijn grootte goed in de hand, wat ingaat tegen de huidige trend van minimalisering en daarnaast meer sympathie uitstraalt.



### Controlepaneel
Omwille van de veiligheid en het gebruiksgemak zit het controlepaneel verwerkt in de middenconsole, de plaats van de vroegere versnellingspook. Dit zorgt voor een vertrouwd en comfortabel gevoel. De posities zijn cirkelvormig verspreid met in het midden de hoofdfunctie. De functies en hun bijhorende posities kunnen naar persoonlijke voorkeur ingesteld worden. Standaard bevindt de navigatie zich in de centrale positie en de temperatuur voor de bestuurder en de passagier respectievelijk links en rechts.



### HUD
Een head-up display (HUD) is een transparant scherm dat informatie projecteert in het gezichtsveld van de bestuurder. Op die manier kunnen gegevens weergegeven worden zonder de blik af te wenden van de baan. Om de afleiding zo beperkt mogelijk te houden is het HUD voorzien van een interface waarop het strikt noodzakelijke aan informatie wordt weergeven. De interface is strak, modern en intuïtief ontworpen, gebaseerd op de noden van de gebruikers.

De linkerkant toont een eenvoudige weergave van de navigatie, waarbij de eerstvolgende instructie zichtbaar is. Centraal staat de huidige snelheid, de toegelaten snelheid en de _lane assist_. De rechterkant wordt vrijgehouden voor de weergave van de functies die bediend worden met de _dial_. Er is een permanent icoon zichtbaar dat aanduidt op welke positie de _dial_ zich op dit moment bevindt.



In een definitief ontwerp wordt het HUD gerealiseerd met augmented reality, navigatiepijlen en andere informatie worden rechtstreeks op de baan geprojecteerd. Zo krijgt de gebruiker niet het gevoel dat het zomaar een visuele weergave is. Het innovatieve aspect van Ctrl-Wheely komt hiermee nog meer tot uiting.

## Kritische reflectie
We hebben ons dit jaar meer dan ooit geconcentreerd op de gebruiker. Door gebruikerstesten altijd uit te voeren in een reële context en de context zo consistent mogelijk te houden, zetten we extra in op de validiteit. De gebruiker werd hierdoor meer op zijn gemak gesteld en kon zich zo beter inleven. Dit maakt de input van de gebruiker concreter, betrouwbaarder en nuttiger. Een nadeel aan het testen tijdens het rijden was dat de gebruiker eerst nog moet wennen aan een wagen die ze niet kennen. Het rijden vergt dan aandacht die op dat moment niet naar de test en in het bijzonder naar ons product kan gaan. Toch zijn we zeer trots op het gerealiseerde eindprototype en staan we meer dan 100% achter de gemaakte ontwerpkeuzes, vertrokken vanuit de feedback van de meest centrale stakeholder: de eindgebruiker. De belangrijkste **approach** was voor ons de contextrealisatie en validiteit, zeker in het tweede semester.

Om volledig terug te blikken moeten we even terug naar het begin van dit project. Al snel werd het gestelde probleem bevestigd door andere autobestuurders en door onderzoek in de ontdekkingsfase. We kregen een eerste duidelijk beeld van het probleeem tijdens een focusgroep en _contextual inquieries_. We konden ons na deze ontdekkingsfase geen betere teamgenoot voorstellen en groeiden doorheen het project uit tot een ijzersterk team van twee enthousiaste, gedreven studenten. We hadden beiden een sterke toekomstvisie over het project. De twee visies kwamen goed overeen en zorgden nooit voor problemen. In de definitiefase konden we ons concept concretiseren aan de hand van weloverwogen _design requirements_. De _dial_ en de interface konden we uitwerken via concrete renders en zo voor een eerste maal voorstellen.

In het tweede semester ging ons concept er met rasse schreden op vooruit. De ene test volgde de andere snel op. Doordat we tijdens de eerste develop-test al een (deels) interactief prototype hadden, konden we niet alleen antropometrische data valideren, maar ook de eerste beperkingen en opportuniteiten van ons concept onder ogen zien. Een goede basis dus voor het tweede deel van de ontwikkelingsfases en de maak van ons eerste interactieve prototype. Het werd een geavanceerd prototype dat de realiteit zo goed mogelijk benaderde en zo de testresultaten zo valide mogelijk maakt. Dat we trots mogen zijn op ons eerste interactief prototype, gemaakt in ProtoPie, werd bevestigd door onze gebruikers en het enthousiasme van de mensen uit de bedrijfswereld tijdens het _industry consult_. Tussen de tweede en de laatste develop-fase kwamen we op een eng doch zeer leerrijk moment. Na het _industry consult_ konden we ons concept helemaal omgooien en dat deden we ook. We kozen, met nog steeds oog op de gebruiker, voor een nog betere en veiligere uitwerking van ons product. Een grote stap die ons ten goede bleek te komen in de laatste testfase. Ondanks dat dit nieuwe prototype niet tot in de details was uitgewerkt, wekte ons concept en prototype alleen maar lof bij de gebruikers.

De laatste test was, zoals het hoort, een bevestigingstest waarin de gemaakte ontwerpkeuzes bevestigd werden door de gebruikers. Natuurlijk waren er ook nog enkele kleine bedenkingen of verbeteringen. Deze laatst aangehaalde puntjes probeerden we nog zoveel mogelijk te realiseren in het eindprototype.

Om ons verslag te eindigen antwoorden we samenvattend nog even op de onderzoeksvraag: **Op welke (gebruiksvriendelijke) manier kunnen we de functies in het dashboard bedienen zonder onze focus op de weg te verliezen?** Wel, dat doen we door gebruik te maken van Ctrl-Wheely. Een fysieke verplaatsbare knop op een controlepaneel in de middenconsole waarmee je de verschillende functies van je auto bedient. Alles wat je aan het bedienen bent wordt weergegeven in een head-up display. 

## Bijlagen
- Discovery
  - Contextual inquiries
    - [protocol](https://ugentbe-my.sharepoint.com/:b:/g/personal/korneel_verraes_ugent_be/EbsFMVmtLS9PsmruQO7G164BsZ5_j9Fu6Rl854Qa3qWmYQ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)
    - [report](https://ugentbe-my.sharepoint.com/:b:/g/personal/korneel_verraes_ugent_be/Eas4YG_7SpxApFeq5h0TQsYBoihKIDYJINAHUwYjbGnJOA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)
  - Focus groups
    - [protocol](https://ugentbe-my.sharepoint.com/:b:/g/personal/korneel_verraes_ugent_be/EWh6baFsMMRGoy3ka52hPG4BzbzurMG2UVsQyipgFQgmfw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)
    - [report](https://ugentbe-my.sharepoint.com/:b:/g/personal/korneel_verraes_ugent_be/EcaQ1q157GFNu4digImXqBoBSc3dnoYHoLg65hIQWaBKaA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)
  - Benchmarking
    - [protocol](https://ugentbe-my.sharepoint.com/:b:/g/personal/korneel_verraes_ugent_be/EXawcWpXBVpEt_lIMpMp_2ABLn8YT56Gweo287PCzCVebw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)
    - [report](https://ugentbe-my.sharepoint.com/:b:/g/personal/korneel_verraes_ugent_be/ES47CYFbTF1EnaaEx6L9F90BNoMAPfkbhsjLT51bKq1DlA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)
- Definition
  - Dial
    - [protocol](https://ugentbe-my.sharepoint.com/:b:/g/personal/korneel_verraes_ugent_be/EXA8tLux91JJgyoZDhd7l8EBiHgo0lbct7zmwVrcxtyVpQ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)
    - [report](https://ugentbe-my.sharepoint.com/:b:/g/personal/korneel_verraes_ugent_be/ES0ZpXk9lqNEglcTKWC2yTYBzBOITMq5B5F91GWfasvyiA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)
  - User interface
    - [protocol](https://ugentbe-my.sharepoint.com/:b:/g/personal/korneel_verraes_ugent_be/EZTgPm-nd4pIsmm8usEYeBUBz1gfDapTBei-XWnFm_MZ7g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)
    - [report](https://ugentbe-my.sharepoint.com/:b:/g/personal/korneel_verraes_ugent_be/EeAsWolB5e9JmBZqcdCANsUBhkX-JtqDsruhD6Gw2MzLAQ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)
- Develop 1
  - [protocol](https://ugentbe-my.sharepoint.com/:b:/g/personal/korneel_verraes_ugent_be/Ed5Cw6uYuAREtow-HiDa7TQBSTC7YIpYGRGnOxcfrB0F6w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)
  - [report](https://ugentbe-my.sharepoint.com/:b:/g/personal/korneel_verraes_ugent_be/ETyGm0r8TDZHsSQlNxfRxxwBqzdG42B0hlqhnKxVS78oCg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)
- Develop 2
  - Expert review
    - [protocol](https://ugentbe-my.sharepoint.com/:b:/g/personal/korneel_verraes_ugent_be/ETqsrg_xHrBOkA1brbJ3t2IBkXsYxzCnGieAo1CWaPYekw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)
    - [report](https://ugentbe-my.sharepoint.com/:b:/g/personal/korneel_verraes_ugent_be/EfVC145y3KxDvudC-U4TsT8BUycW9wZWifMW9NHYxgdx_A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)
  - Usability test
    - [protocol](https://ugentbe-my.sharepoint.com/:b:/g/personal/korneel_verraes_ugent_be/EV5OZfwtGPBFrt3uwZXcVNcBihPvPzmzFxCDzjzQltVrZA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)
    - [report](https://ugentbe-my.sharepoint.com/:b:/g/personal/korneel_verraes_ugent_be/EeRQD4A97TdJoxIuUXeTQNYBUtt4XM00AD7CwpS1mvPMRg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)
- Develop 3
  - [protocol](https://ugentbe-my.sharepoint.com/:b:/g/personal/korneel_verraes_ugent_be/EXClvOz8INdJgKvF5UcQUhIBYpvQ8Hyk5CacbJ5YMebfbQ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)
  - [report](https://ugentbe-my.sharepoint.com/:b:/g/personal/korneel_verraes_ugent_be/EdHE8VL7fB5EkfIlp2sKCNsBZ6HWYYmyrerdYaaHGuqJ-A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)

## Bronnen
[^1]: Beeckman, H. (2021, 11 maart). *Aanraakschermen in je auto bedienen drie keer gevaarlijker dan rijden onder invloed: “Europese regels nodig”.* VRTNWS. https://www.vrt.be/vrtnws/nl/2021/03/11/aanraakschermen-in-je-auto-bedienen-drie-keer-gevaarlijker-dan-r/
[^2]: TRL (2019, 15 april). *Distracted Driving Evidence Has Fallen Behind the Latest Technological Changes.* TRL. https://www.trl.co.uk/news/distracted-driving-evidence-has-fallen-behind-the-latest-technological-changes
[^3]: Rotmans, M. (2005). *DINBelg 2005* [Dataset]. https://www.dinbelg.be/DINBelg%202005%20antropometrie%20tabel.PDF

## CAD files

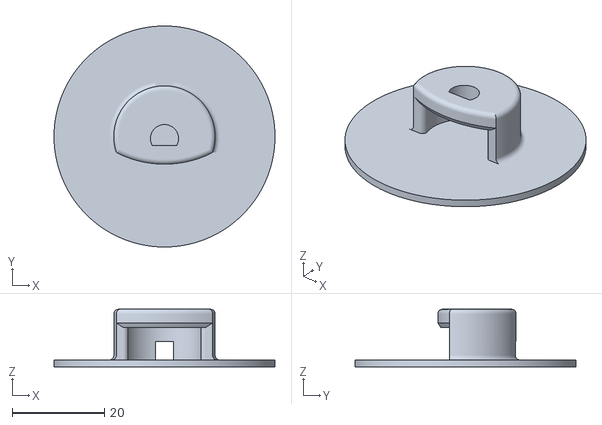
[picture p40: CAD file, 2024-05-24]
files/dial onderkant.stl
48.0 x 48.0 x 12.5

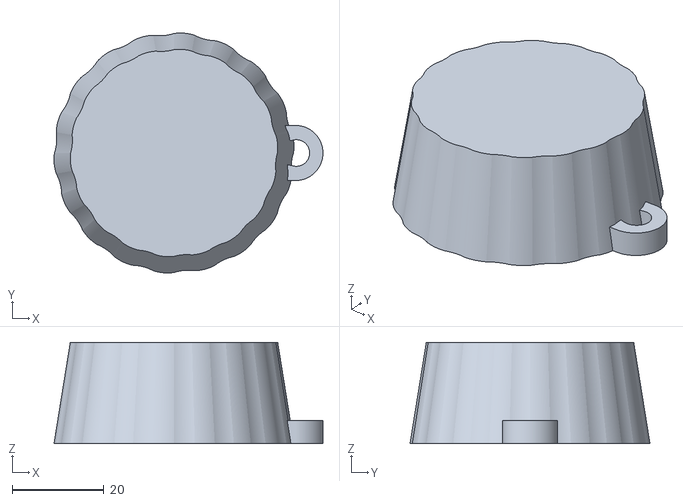
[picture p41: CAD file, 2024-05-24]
files/dial autosleutel.stl
58.5 x 52.2 x 22.0

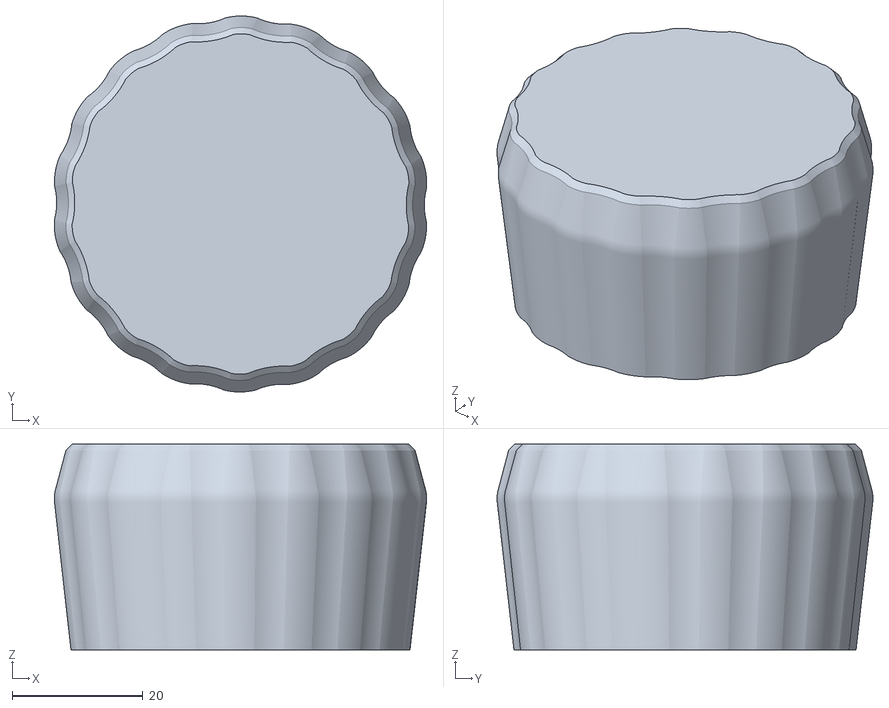
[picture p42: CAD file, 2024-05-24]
files/dial bovenkant.stl
57.0 x 57.5 x 31.5
